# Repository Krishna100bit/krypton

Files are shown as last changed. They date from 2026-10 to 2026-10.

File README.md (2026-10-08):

# OpenPendant

Open-source DIY AI audio pendant. Firmware runs on a **Seeed XIAO nRF52840 Sense**. The necklace captures audio and streams 16 kHz PCM over BLE. Speech-to-text runs on the **phone or laptop**. The MCU never holds an API key.

Record only with an obvious LED and an explicit host subscribe (GATT notify on = recording).

## Hardware

| Part | Notes |
|---|---|
| Seeed XIAO nRF52840 Sense | nRF52840 + onboard PDM mic + LSM6DS3TR-C IMU |
| microSD SPI/SDIO module | 8-pin breakout; VCC = **3V3 only** (never 5V) |
| Ø6 tactile button | 2-pin NO; COM → GND, NO → D1 |
| 22 µF capacitor | Across SD **3V3** and **GND** (16 V ceramic preferred) |
| Perfboard strip | ~8 × 18 holes; XIAO + SD on the front, LiPo on the back |
| WLY602030 1S LiPo | 3.7 V nominal, 300 mAh, 6 × 20 × 30 mm. Open-wire to **BAT+/BAT−**. USB-C charges via BQ25101. |
| USB-C cable | Dev and UF2 flash |

Assembly guide (photos, 3D viewer, printable case): [`docs/pendant_assembly.html`](docs/pendant_assembly.html).

### Wiring (USB at the bottom)

Pin map with the component face toward you:

```text
  XIAO                              microSD (SPI)
  ----                              -------------
  D9  (SCK)  ---------------------> CLK
  D8  (MOSI) ---------------------> CMD
  D7  (MISO) ---------------------> D0
  D6  (CS)   ---------------------> D3
  3V3 ----------------------------> 3V3
  GND ----------------------------> GND
                                    D1, D2  (leave open)

  Button NO  ---------------------> D1
  Button COM ---------------------> GND

  22 µF  across SD 3V3 ↔ SD GND

  LiPo red  --> BAT+     (through the BAT window, last)
  LiPo black -> BAT−
```

```text
Left (USB bottom)     Right (USB bottom)
─────────────────     ──────────────────
5V   (empty)          D0
GND                   D1  button NO
3V3 ──► SD 3V3        D2
D10                   D3
D9  ──► SD CLK        D4  (IMU SDA — do not use)
D8  ──► SD CMD        D5  (IMU SCL — do not use)
D7  ──► SD D0         D6 ──► SD D3 (CS)
```

Firmware remaps SPI2 onto **D9 / D8 / D7** (not the board silk SPI defaults D8 / D10 / D9) and disables UART0 so it cannot steal **D6 / D7**. After soldering, flash over USB (no cell required) and run **Settings → Developer → Run SD test** with a FAT32 card.

## What you get

- **Firmware** (Zephyr / nRF Connect SDK 3.4, Zephyr 4.4): BLE GATT PCM + status, IMU still-sleep (mic off when the board is still, wake on motion), battery voltage / SoC estimate, microSD FAT R/W self-test.
- **Flutter app** in [`app/`](app/): meetings and hold-to-talk notes over BLE, local VAD, **Saaras v4** or on-device **Qwen3-ASR**, optional **OpenAI diarization**, reminders, daily briefings and recaps, persistent follow-ups, Memories search, and local SQLite. Double-click the pendant to ring the connected phone.
- **Laptop tools** in [`tools/`](tools/): BLE capture to WAV, OpenAI or local Whisper.

Protocol, clip schema, and roadmap: [project_context.md](project_context.md). Later sync sketch: [docs/sync_api.md](docs/sync_api.md).

## Firmware

Requires [nRF Connect SDK v3.4.0](https://docs.nordicsemi.com/bundle/ncs-latest/page/nrf/installation.html). Use the Nordic SoftDevice Controller only — do **not** enable `CONFIG_BT_LL_SW_SPLIT` on this board (USB CDC breaks).

```bash
west build -b xiao_ble/nrf52840/sense -d build .
```

Double-tap RESET so the volume `XIAO-SENSE` appears. Finder copy often fails; `dd` works:

```bash
dd if=$(find build -name zephyr.uf2 | head -1) of=/Volumes/XIAO-SENSE/CURRENT.UF2 bs=4096
```

Serial (macOS `screen` often hangs up CDC):

```bash
python3 -m serial.tools.miniterm /dev/cu.usbmodem1101 115200
```

BLE advertises as **OpenPendant**. Disconnect nRF Connect before the app or laptop capture (one connection).

Control UUID `70301104-…`: write `1` / `0` for find-pendant LED flash; write `2` to run the SD mount / write / read test (result in status bytes 8–9).

## Flutter app

```bash
cd app
flutter pub get
flutter run -d macos          # BLE works on Mac
# or a physical iPhone / Android — not the iOS simulator
```

Paste a **Sarvam** key in **Settings** (required for cloud transcripts) and an **OpenAI** key for diarization, day Clean, Memories, and meeting Recap. Keys stay on the host (Keychain / Keystore / app-support file on desktop), never on the pendant.

**Typical day**

1. Connect. Optional **Calibrate** (wear as usual, read the script) sets a personal VAD floor for **notes** only.
2. Optional **Voices**: enroll up to 4 people (2–10 s sample each) if you want named speakers. Turn **Diarization** on in Settings.
3. Start a **meeting** (pendant click, or **Start meeting** in the app) or take a **note** (hold the pendant ~0.7 s, or **Take a note** on the phone). Say “remind me to … at 10 AM” and the phone notifies 15 minutes before; notes without a time come back in an 8 AM reminder until you check them off. **Double-click** rings the connected phone so you can find it. **Find pendant** (connected sheet or Settings → More) is closer/farther from BLE signal, not a compass. Notify stays on while a meeting is armed; LED stays solid. Chunks rotate on IMU sleep, ~30 s raw, or quiet after speech. Local VAD skips the cloud when there is no speech. Meetings use a fixed energy floor (`1e9`, ~0.5 s of speech) so people a metre or two from the chest mic still pass; hiss still has to look like voice. Wearer calibrate does not raise that meeting gate. Double-click a meeting title to rename it.
4. **Transcription:** Settings can use **Saaras v4** (cloud) or **on-device Qwen3-ASR**. Both store the engine text as returned (Hindi in Devanagari when that is what came back). Diarization stays OpenAI and applies to Saaras meetings only. Stop the meeting when you are done. Home groups chunks into one transcript; with diarization on, a long Saaras phrase is split at OpenAI speaker-change times. The transcript tab shows **Transcribing…** until STT catches up.
5. **Close the day:** Home surfaces pending notes and open loops. Tap **Close today** to clean the day’s stored text and create chapters, decisions, follow-ups, and a Memories-ready recap. Follow-ups become checkable notes and join the 8 AM digest until completed. Open the saved review and use **Refresh recap** to replace it after recording more; each run uses OpenAI.

More setup (permissions, IMU debug): [app/README.md](app/README.md).

## Laptop capture

```bash
python3 -m pip install -r tools/requirements.txt
export OPENAI_API_KEY=          # optional; omit for local Whisper
python3 tools/capture_pcm.py --seconds 8 --out capture.wav && \
  python3 tools/transcribe.py capture.wav --backend openai
```

Local Whisper:

```bash
python3 tools/transcribe.py capture.wav --backend local
```

## Consent and sleep

- **Recording:** enable PCM notify. The red LED stays solid while subscribed (armed).
- **IMU sleep:** after ~10 s still, firmware stops the PDM mic and PCM. BLE stays up. Motion wakes the mic. Host VAD drops non-speech before STT.
- **App Sleep** is a BLE disconnect, not IMU sleep.

## Battery

Solder the WLY602030 **red** lead to **BAT+** and **black** to **BAT−** (polarity matters; open wire, no JST). USB-C charges the cell through the XIAO BQ25101. Connect the cell **last**, after the SD / button joints meter clean on USB.

The cell has no fuel-gauge IC. Firmware measures pack voltage (P0.31, 1 MΩ / 510 kΩ divider) and the app maps that to a **rough SoC only when USB is unplugged**. On USB the BQ25101 rail reads ~4.1 V even with no cell, so the UI shows **USB** instead of a fake percent. Treat ~20% as “charge soon.” Keep P0.14 low whenever a cell is attached (firmware hog does this) so P0.31 stays within 3.6 V.

## License

[Apache License 2.0](LICENSE).

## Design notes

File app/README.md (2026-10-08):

# OpenPendant Flutter app

Host for the necklace: arm once → BLE PCM chunks → local VAD → OpenAI → SQLite sessions with wall-clock segments.

## Setup

```bash
cd app
flutter pub get
flutter run -d macos
```

On a phone, use a physical device (BLE does not work in the iOS simulator). A **debug** build cannot be opened from the Home Screen; use `flutter build ios --release` (or profile) for that. If Xcode says the bundle ID `com.openpendant.openpendant` is taken, set a unique id under **Signing & Capabilities** for your Personal Team (do not commit that id).

```bash
flutter devices
flutter run
```

Paste API keys in **Settings**. **Sarvam** is required for cloud transcripts (Saaras v4). Or switch **Transcription** to **On-device** Qwen3-ASR 0.6B (~1 GB once). Transcripts are saved as the engine returns them. **OpenAI** is used for optional meeting diarization (Saaras path only), day Clean, Memories, and meeting Recap.

Disconnect nRF Connect first (the pendant allows one BLE connection). Optional **Auto-connect** in Settings → Behavior links the necklace when it is nearby and the app is open (off by default).

**Find phone:** double-click the pendant button while connected. The phone plays a looping tone (ignores the iOS silent switch) until you tap the screen, double-click again, or 40 seconds pass. Leave the app in the switcher; a force-quit will not receive the button.

**Find pendant:** from the connected sheet or Settings → More. Walk and watch the ring — a stronger BLE signal means closer. It cannot point a compass direction. Current firmware also flashes the board LEDs while you search.

**Note reminders:** “remind me to call mom at 10 AM” notifies 15 minutes before (or 5 minutes / at due if you are already close). Reminder-shaped speech is saved as a **to do**. Everything else is a **thought** (idea / observation) with no checkbox. Library → Notes is a chronological feed with All / Thoughts / To do filters; convert between kinds from the row menu. Untimed to-dos are included in an 8 AM digest until you check them off. iOS will ask for notification permission the first time a reminder is scheduled.

**Daily review:** Home’s briefing surfaces the next pending note and unfinished work. **Close today** sends that day’s stored transcript text and notes to OpenAI, saves a structured recap, and promotes follow-ups/open loops into checkable notes. The recap feeds Memories and optionally Mem0. Open the day review and tap refresh to replace the recap after more recording; refreshing does not create recap copies, but it does use OpenAI again.

If `flutter run` fails with `failed to create ... /.config/flutter`, your `~/.config` may be owned by root:

```bash
sudo chown -R "$(whoami)" ~/.config
mkdir -p ~/.config/flutter
```

On macOS, Xcode must finish first-launch (missing `CoreSimulator` causes `xcodebuild` to fail):

```bash
sudo xcode-select -s /Applications/Xcode.app/Contents/Developer
sudo xcodebuild -runFirstLaunch
brew install cocoapods   # if Flutter reports CocoaPods missing
```

This app disables Swift Package Manager in `pubspec.yaml` because `flutter_secure_storage_macos` does not support it yet.

## Permissions

iOS `ios/Runner/Info.plist`:

- `NSBluetoothAlwaysUsageDescription` / `NSBluetoothPeripheralUsageDescription`
- `UIBackgroundModes`: `bluetooth-central` and `audio` so pendant buttons (including find-phone) and capture still work when the phone is locked (leave the app in the switcher; a force-quit will not wake)
- Local notifications: the first scheduled reminder prompts for alert permission. Timed notes and the morning digest still fire if the app is in the background.

Android `AndroidManifest.xml`:

- `BLUETOOTH`, `BLUETOOTH_ADMIN`, `BLUETOOTH_SCAN`, `BLUETOOTH_CONNECT`, `ACCESS_FINE_LOCATION` (pre-12)
- `POST_NOTIFICATIONS`, `RECEIVE_BOOT_COMPLETED`, `SCHEDULE_EXACT_ALARM` for note reminders

## Consent and armed capture

**Record** = arm: GATT notify on, LED solid, one session id. Capture keeps running until **Stop** or **Sleep**.

Chunks rotate on IMU sleep, ~30 s of raw buffer, or quiet after speech. Each chunk is VAD-gated; silence is not sent to STT. After transcription succeeds or fails, clip WAV files are deleted. Home stitches session text and shows STT spend. While a clip is still in the STT queue, the meeting UI shows **Transcribing…** instead of an empty transcript.

**Meetings** use a fixed VAD energy floor (`VadGate.meetingEnergyFloor` = `1e9`) and at least **0.5 s** of speech-shaped audio. That is about 10× more sensitive than the note default (`1e10`), so quieter / farther talkers on the Knowles SPU0410 chest mic still reach STT. Spectral checks (speech-band ratio and centroid) still drop hiss and rumble. Wearer **Calibrate** does not change the meeting floor.

**Take a note** in the app is tap-to-start / tap-to-save. Pendant BLE still reports `noteHeld: false` while you are not holding the hardware button; those status packets must not stop an in-app note. Hold-to-talk on the necklace is unchanged.

## Mic calibrate

**Calibrate** (home): wear the pendant as you will all day, read the script. The host measures speech-band energy at your mouth–mic distance and sets a personal VAD energy floor for **notes** (saved on this device). Re-calibrate if how you wear it changes. Meetings ignore this floor.

## Voices (speaker names)

**Voices**: enroll up to 4 people (2–10 s sample + name). When **Diarization** is on, meeting clips go to `gpt-4o-transcribe-diarize` with those references; speaker labels are stamped onto the Saaras transcript by time, and a single long Saaras phrase is split at OpenAI speaker-change times. Notes stay on Saaras only (no speaker prefix in the note text).

## IMU sleep debug

After flashing firmware that includes status UUID `70301103-…`, Connect (Record is not required). The **Debug** card shows IMU SLEEP/AWAKE, mic, still meter, battery/USB, and VAD calibrate status.

- Leave the board still ~10 s → IMU **SLEEP**, mic **stopped**.
- Pick it up → **AWAKE**. Mic noise does not block sleep.
- App **Sleep** is a BLE disconnect, not IMU sleep.

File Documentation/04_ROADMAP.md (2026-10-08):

# 04 — Roadmap (Phases, Tracks, Gates)

## 1. How to read this
24 hours, a team, mostly vibe-coded. Work is split into **phases (P0–P11)**, each small enough for one AI-assisted session (30–120 min), with a clear **exit criterion**. Four parallel **tracks**: **A** Flutter app, **B** Backend/AI, **C** Hardware + integration, **D** Pitch/QA.

Priority tags: **[CORE]** required by PS 04 · **[DIFF]** differentiator · **[STRETCH]** cut first.

## 2. Phase table
| Phase | Name | Track | Time box | Depends on | Tag |
|---|---|---|---|---|-----|
| P0 | Foundations, repo audit, contracts | All | 0:00–1:30 | – | CORE |
| P1 | AI core on text (zoning + extraction) | B | 1:30–5:00 | P0 | CORE |
| P2 | ASR + job pipeline + API | B | 3:00–8:00 | P0 | CORE |
| P3 | Flutter capture abstraction + phone recording + upload | A | 1:30–7:00 | P0 | CORE |
| P4 | Zone viewer + minutes UI | A | 6:00–12:00 | P1, P3 | CORE |
| P5 | Locket as AudioSource | C | 6:00–11:00 | P3 | CORE (PS differentiator) |
| P6 | Reminders engine + notifications | A | 9:00–13:00 | P4 | DIFF |
| P7 | Email drafts + approval gate + calendar | A+B | 11:00–15:00 | P4 | DIFF |
| P8 | Speaker enrollment, test, identification | B+A | 10:00–16:00 | P2 | DIFF |
| P9 | Memory search + recap Q&A | B+A | 14:00–18:00 | P2, P4 | DIFF |
| P10 | Offline tiers: Ollama (B) then on-device SLM (C) | B+A | 16:00–20:00 | P9 | STRETCH |
| P11 | Thoughts + daily closing summary | A+B | 18:00–21:00 | P9 | STRETCH |
| P12 | Freeze, polish, demo, pitch, backup video | All | 21:00–24:00 | – | CORE |

## 3. Gates (stop and check)
| Gate | Time | Must be true | If not |
|---|---|---|---|
| G0 | 1:30 | Contracts in repo, fixtures exist, app builds and runs, BLE audit written | Fix before anything else |
| G1 | 5:00 | Text transcript → valid minutes JSON for 3 fixtures | Simplify prompt; use few-shot; smaller schema |
| G2 | 8:00 | Audio file → minutes via API | Use `base` Whisper; skip diarization for now |
| G3 | 12:00 | **Phone recording → upload → zone viewer + minutes works on a real phone** | Drop all stretch work; fix this |
| G4 | 15:00 | Locket recording works OR fallback decided | Ship phone + upload; demo locket as pre-recorded clip |
| G5 | 18:00 | At least 2 of: speaker ID, reminders, drafts, memory working | Cut remaining DIFF items |
| G6 | 21:00 | **Feature freeze** | Only bug fixes after this |

## 4. Phase details
Each phase lists: Goal · Tasks · Deliverables · Exit criteria.

### P0 — Foundations (0:00–1:30)
- Fork/clone the OpenPendant repo into `app/`; run the app on a physical Android phone.
- **Audit:** find BLE service UUIDs, audio characteristic, codec handling, recording storage, any Firebase/auth/backend dependencies (see file 05 §2).
- Create `contracts/minutes.schema.json`, `openapi.yaml` stubs, `contracts/fixtures/` with 3 sample transcripts + expected JSON.
- Put `AGENTS.md` (file 08) in repo root; create `.env.example`.
- Exit: app runs; audit notes written; schema agreed by A and B.

### P1 — AI core on text (1:30–5:00) · Track B
- Implement `LLMClient`, Pydantic models from schema, zoning + extraction prompts (file 06).
- Script `eval/run_eval.py` comparing output with golden fixtures.
- Validator: utterance coverage, no gaps/overlaps, enum checks, date resolution.
- Exit: 3 fixtures produce valid JSON; coverage validator passes; first eval numbers recorded.

### P2 — ASR + pipeline + API (3:00–8:00) · Track B
- `faster-whisper` wrapper with word timestamps → utterances.
- FastAPI endpoints: health, create meeting (audio/transcript), job status, get meeting.
- Job runner with stages and progress.
- Exit: `curl` upload of a WAV returns minutes JSON in a reasonable time.

### P3 — Flutter capture + upload (1:30–7:00) · Track A
- `AudioSource`, `PhoneMicSource`, `RecordingSession`, `WavWriter` (file 05).
- Permissions, foreground service, home screen, record screen with timer + level meter.
- Drift DB with meetings; upload queue with retry; job polling.
- Exit: record 30 s on phone → file on disk → upload works against the stub/real backend.

### P4 — Viewer + minutes UI (6:00–12:00) · Track A
- Meeting list; Meeting detail with tabs: **Transcript (zones)** and **Minutes**.
- Zone colours, legend filter, tap-to-scroll, speaker chips, editable actions table, export.
- Exit: fixture JSON renders correctly; live meeting from P2 renders end to end.

### P5 — Locket source (6:00–11:00) · Track C
- Wrap the existing BLE+Opus code as `LocketBleSource` emitting PCM16 16 kHz.
- Source selector UI, health indicator, disconnect handling, "Continue on phone".
- Exit: 60 s locket recording → WAV plays back clearly → minutes generated.

### P6 — Reminders (9:00–13:00) · Track A
- `ReminderRules.compute()` pure Dart + unit tests; `ReminderScheduler` with notifications; reschedule on edit; overdue nudge.
- Exit: all rule test cases pass; real notification fires on phone (use a test deadline 3 minutes away).

### P7 — Email drafts + approval + calendar (11:00–15:00)
- Backend `draft-email` endpoint; app `DraftStateMachine`; Review & Send screen; confirm dialog; `mailto:`/intent handoff; calendar insert.
- Exit: draft generated, edited, **cannot be sent without the confirm tap** (unit test proves it), handoff opens mail app with content.

### P8 — Speakers (10:00–16:00)
- Enroll endpoint + embeddings; test-sample endpoint + screen; diarize + match in pipeline; rename + auto-enroll.
- Exit: two enrolled teammates are named correctly in a 2-person clip; score shown.

### P9 — Memory + recap (14:00–18:00)
- Chunk/embed on server; `/ask` with citations; app Ask screen; FTS5 index for offline.
- Exit: three prepared questions return correct cited answers.

### P10 — Offline tiers (16:00–20:00)
- B: Ollama client + app tier switch + demo over hotspot with internet off.
- C: model download manager, `local_slm.dart` recap from structured minutes, graceful "unavailable" state.
- Exit: B demonstrated; C either working or visibly marked Experimental.

### P11 — Thoughts + daily summary (18:00–21:00)
- Thought button + voice trigger detection; recap + research + brainstorm.
- `DailySummary` template builder + 21:00 notification; optional SLM/LLM polish.
- Exit: one thought end to end; summary notification fires.

### P12 — Freeze and ship (21:00–24:00)
- Bug bash with checklist (file 09), seed demo data, record backup video, rehearse pitch ×3, build release APK, charge phone, pack cables.

## 5. Cut lines (in order)
1. On-device SLM (keep Tier B) → 2. Thoughts research/brainstorm → 3. Daily summary polish → 4. Names vault → 5. Gmail API (keep mailto) → 6. Speaker auto-enroll → 7. Locket live (keep pre-recorded locket clip).
**Never cut:** phone recording, zone viewer, minutes, approval gate, one reminder demo.

## 6. Team allocation
| Role | People | Owns |
|---|---|---|
| Flutter lead | 1–2 | P3, P4, P6, P7 UI |
| AI/backend lead | 1 | P1, P2, P8, P9 |
| Hardware/integration | 1 (VENOM likely) | P5, P10-B, deployment, final demo rig |
| Pitch/QA | 1 | file 09, slides, test data |
Solo? Order: P0 → P1 → P2 → P3 → P4 → P6 → P5 → P7, then whatever time allows.

## 7. Post-hackathon roadmap
v2.1 sync + accounts + encrypted storage · v2.2 streaming live captions · v2.3 battery + enclosure + LED + VAD firmware · v2.4 Slack/Notion/Calendar API integrations · v2.5 iOS · v3 team workspaces, multilingual, fine-tuned zoning model.

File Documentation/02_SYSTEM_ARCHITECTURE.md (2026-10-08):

# 02 — System Architecture

## 1. Context diagram
```mermaid
flowchart LR
  subgraph Wearable
    L[XIAO nRF + mic<br/>OpenPendant firmware]
  end
  subgraph Phone[Flutter App]
    SRC[AudioSource<br/>PhoneMic / LocketBLE]
    REC[RecordingSession + WAV writer]
    DB[(SQLite + FTS5)]
    ROUTER[InferenceRouter]
    REM[Reminder Engine<br/>rule-based]
    SLM[On-device ASR + SLM<br/>optional]
    UI[Viewer / Minutes / Ask / Drafts]
  end
  subgraph Server[Backend: laptop or cloud]
    API[FastAPI]
    ASR[faster-whisper]
    DIA[pyannote + SpeechBrain]
    LLM[LLM: Claude API or Ollama]
    VEC[(Chroma + SQLite)]
  end
  EXT[Calendar app / Mail app / Gmail drafts / Search API]
  L -- BLE Opus --> SRC
  SRC --> REC --> DB
  REC --> ROUTER
  ROUTER -- Tier A/B --> API
  ROUTER -- Tier C --> SLM
  API --> ASR --> DIA --> LLM --> VEC
  API -- minutes JSON --> DB
  SLM --> DB
  DB --> UI
  DB --> REM
  UI -- user taps --> EXT
```

## 2. Components
| Component | Responsibility | Tech |
|---|---|---|
| Firmware | Capture mic, Opus encode, stream over BLE (unchanged from v1) | nRF Connect SDK / Zephyr (existing) |
| AudioSource layer | Uniform PCM stream from either input | Dart |
| RecordingSession | Chunked WAV on disk, level meter, duration, recovery | Dart |
| InferenceRouter | Chooses Tier A/B/C from connectivity and settings | Dart |
| Backend API | Jobs, pipeline, memory, drafts | FastAPI |
| ASR | Timestamped transcript | faster-whisper |
| Diarization + Speaker ID | Turns + names | pyannote 3.1, SpeechBrain ECAPA |
| LLM service | Zoning, extraction, recap, drafts, intent | Claude API / Ollama (Qwen, Llama) behind one interface |
| Memory | Chunk, embed, retrieve, cite | Chroma + bge-small; FTS5 on device |
| Reminder Engine | Deterministic scheduling | Dart + flutter_local_notifications |
| Draft Manager | Draft state machine + approval gate | Dart |
| Scheduler | Daily summary, overdue nudges | Local notifications |

## 3. Key data flows

### 3.1 Record → minutes
```mermaid
sequenceDiagram
  participant U as User
  participant A as App
  participant S as Backend
  U->>A: Tap Record (Phone or Locket)
  A->>A: AudioSource -> WAV (16k mono)
  U->>A: Stop
  A->>A: Save meeting row (status=recorded)
  A->>S: POST /v1/meetings (audio)
  S-->>A: meeting_id, job_id
  S->>S: ASR -> diarize -> speaker match
  S->>S: LLM zoning + extraction (validated JSON)
  S->>S: Chunk + embed for memory
  A->>S: poll /v1/jobs/{id}
  S-->>A: minutes JSON
  A->>A: Store, index FTS5, schedule reminders
  A-->>U: Zone viewer + minutes
```

### 3.2 Action → reminder (fully local)
Action saved with deadline + priority → `ReminderRules.compute()` → rows in `reminders` → `zonedSchedule` notifications. Editing the action cancels and recomputes. No network involved.

### 3.3 Action → email draft with human approval
```mermaid
stateDiagram-v2
  [*] --> GENERATED: tap "Draft email" (LLM or template)
  GENERATED --> EDITED: user edits
  GENERATED --> DISCARDED
  EDITED --> PENDING_APPROVAL: user opens Review & Send
  GENERATED --> PENDING_APPROVAL
  PENDING_APPROVAL --> APPROVED: user taps "Send" in confirm dialog
  PENDING_APPROVAL --> EDITED: back
  APPROVED --> SENT: mail client / Gmail API returns success
  APPROVED --> FAILED
```
Only `APPROVED` may call the send/handoff function, and `APPROVED` can only be set by a tap in the confirm dialog (see file 07).

### 3.4 Ask memory
Query → (online) embed + Chroma top-k + LLM answer with citations; (offline) FTS5 BM25 top-k → SLM or extractive answer from structured minutes.

## 4. Deployment topologies
| Tier | Where AI runs | Internet needed | Use |
|---|---|---|-----|
| A Cloud | Backend with Claude API + faster-whisper | Yes | Best quality, main demo |
| B Local server | Laptop backend + Ollama (Qwen/Llama) + faster-whisper, phone on same hotspot/LAN | No | "Offline" demo with strong quality |
| C On-device | whisper.cpp/sherpa-onnx + small LLM on phone | No | Offline recap; stretch |

Fallback chain: A → B → C → "recorded, will process later" queue.

## 5. Failure modes and mitigations
| Failure | Detection | Behaviour |
|---|---|---|
| BLE drop | No packets for 3 s | Banner, keep partial WAV, offer Continue on phone |
| Backend unreachable | Timeout / health check | Queue upload, retry with backoff, fall to next tier |
| LLM invalid JSON | Pydantic validation fails | Repair prompt once, then cached/simple heuristic zoning |
| Whisper slow | Job progress stalls | Smaller model option, chunked processing |
| Notification permission denied | Runtime check | In-app banner explaining; reminders listed in-app |
| Exact alarm not permitted | Android check | Fall back to inexact scheduling, warn user |
| App killed mid-recording | Partial WAV exists on restart | Recovery dialog to finalize |

## 6. Security and privacy
- Consent prompt + recording indicator (UI badge; LED if firmware supports it).
- API keys only on the backend; the app uses a single backend URL + a shared secret token for the hackathon.
- Data at rest: app-private storage; delete cascades to audio, transcript, embeddings.
- No automatic outbound messages. Network egress is limited to our backend and optional search for thoughts.
- Logs never contain transcript text in production mode.

## 7. Observability (cheap but useful)
Per-job timings (ASR, diarize, LLM), model names, token counts, validation failures; a `/debug` page in the backend and a hidden debug screen in the app showing the last job JSON.

## 8. Post-hackathon scaling notes
Accounts + sync, queue (Redis/RQ), object storage, streaming ASR, per-user vector stores, encrypted storage, iOS, enclosure + battery, firmware VAD to save power.

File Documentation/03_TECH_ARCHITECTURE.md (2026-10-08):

# 03 — Technical Architecture

## 1. Stack summary
| Layer | Choice | Notes |
|---|---|---|
| Mobile app | Flutter (existing OpenPendant app) | Keep its state management (likely Provider); do not migrate |
| BLE | `flutter_blue_plus` (or whatever the repo already uses) | Keep existing connection code |
| Audio decode | Existing Opus decode path in the repo (e.g., `opus_dart`/`opus_flutter`) | Verify in P0 |
| Phone recording | `record` package (`startStream`, PCM16, 16 kHz, mono) | |
| WAV writing | Own small `WavWriter` (44-byte header + PCM) | |
| Local DB | `drift` (SQLite) + FTS5 | Local-first |
| HTTP | `dio` with retry interceptor | |
| Notifications | `flutter_local_notifications` + `timezone` | Exact alarms on Android |
| Calendar | `add_2_calendar` (native insert screen) | User confirms |
| Email handoff | `url_launcher` `mailto:` / Android share intent; optional Gmail API `drafts.create` | Human-final |
| Foreground service | `flutter_foreground_task` | Long recordings |
| Backend | Python 3.11, FastAPI, Pydantic v2, Uvicorn | |
| Jobs | FastAPI `BackgroundTasks` + SQLite job table | Redis only if time |
| ASR | `faster-whisper` (`small` default, `medium`/`large-v3` if GPU) | CTranslate2 |
| Diarization | `pyannote.audio` 3.1 (HF token) | Or WhisperX |
| Speaker embeddings | SpeechBrain `spkrec-ecapa-voxceleb` | Enrollment + matching |
| LLM (A) | Claude API | JSON-structured output with validation |
| LLM (B) | Ollama: `qwen2.5:7b-instruct` or `llama3.1:8b` | Local server |
| SLM (C) | Qwen2.5-1.5B-Instruct Q4_K_M (≈1 GB, Apache-2.0) or Gemma-class 1–2B | On phone; check license and size |
| On-device ASR (C) | whisper.cpp (`tiny.en`/`base.en`) or sherpa-onnx | Stretch |
| Embeddings | `bge-small-en-v1.5` or `all-MiniLM-L6-v2` | Server |
| Vector store | ChromaDB (persistent) | Server |
| Research | Tavily (or similar) search API | Thoughts only |
| Tests | pytest, `flutter test`, eval script | |

> Always verify package names, versions and licenses against pub.dev / PyPI / model cards on day 0. Packages in the on-device LLM space move fast.

## 2. Flutter app architecture (feature-first layers)
```
app/lib/
├─ core/            # env, theme, router, di, logger, permissions
├─ audio/
│  ├─ audio_source.dart            # abstract interface
│  ├─ phone_mic_source.dart
│  ├─ locket_ble_source.dart       # wraps existing BLE+Opus code
│  ├─ recording_session.dart       # owns source, WavWriter, timers
│  └─ wav_writer.dart
├─ data/
│  ├─ db/ (drift tables, DAOs, FTS5)
│  ├─ api/ (dio client, DTOs generated from contracts)
│  └─ repositories/ (meetings, actions, speakers, thoughts, drafts)
├─ ai/
│  ├─ inference_router.dart        # Tier A/B/C selection
│  ├─ remote_pipeline.dart
│  └─ local_slm.dart               # optional
├─ domain/
│  ├─ models/ (Meeting, Segment, Action, Decision, Draft…)
│  ├─ reminder_rules.dart          # pure Dart, fully unit tested
│  ├─ daily_summary.dart           # pure Dart template builder
│  └─ draft_state_machine.dart
├─ features/
│  ├─ home/  record/  meetings/  viewer/  minutes/
│  ├─ actions/  drafts/  ask/  thoughts/  speakers/  settings/
└─ main.dart
```
Rules: UI never calls BLE or HTTP directly; features call repositories/services. `domain/` has no Flutter imports (testable).

### AudioSource interface
```dart
abstract class AudioSource {
  String get id;                       // 'phone' | 'locket'
  Stream<Uint8List> get pcm16;         // 16 kHz mono little-endian PCM16
  Stream<SourceHealth> get health;     // connected, rssi, dropped packets, level
  Future<void> start();
  Future<void> stop();
}
```

## 3. Backend architecture
```
backend/app/
├─ main.py
├─ api/        meetings.py speakers.py ask.py actions.py thoughts.py summary.py health.py
├─ pipeline/   ingest.py asr.py diarize.py speaker_match.py zone.py extract.py chunk.py
├─ llm/        base.py claude_client.py ollama_client.py prompts/ schemas.py
├─ speakers/   enroll.py embeddings.py
├─ memory/     store.py retrieve.py answer.py
├─ jobs/       runner.py models.py
├─ core/       config.py db.py logging.py
└─ tests/
```
`llm/base.py` defines `LLMClient.generate_json(system, user, schema) -> dict` so Tier A and B are interchangeable.

## 4. Data schemas

### 4.1 App DB (SQLite via drift)
```sql
meetings(id TEXT PK, title TEXT, started_at INT, duration_s INT, source TEXT,        -- phone|locket|upload
         audio_path TEXT, status TEXT,                                               -- recorded|uploading|processing|ready|failed
         summary TEXT, minutes_json TEXT, server_id TEXT);
utterances(id TEXT PK, meeting_id TEXT, idx INT, speaker_id TEXT, start_s REAL, end_s REAL, text TEXT);
segments(id TEXT PK, meeting_id TEXT, idx INT, zone TEXT,                            -- discussion|decision|action
         start_idx INT, end_idx INT, start_s REAL, end_s REAL, summary TEXT, confidence REAL);
decisions(id TEXT PK, meeting_id TEXT, segment_id TEXT, text TEXT, decided_by TEXT, rationale TEXT);
actions(id TEXT PK, meeting_id TEXT, segment_id TEXT, task TEXT, owner_name TEXT, owner_speaker_id TEXT,
        owner_inferred INT, deadline_ts INT NULL, deadline_inferred INT, priority TEXT, status TEXT,   -- open|done|snoozed
        source_quote TEXT, created_at INT);
reminders(id TEXT PK, action_id TEXT, fire_at INT, kind TEXT, notif_id INT, state TEXT);              -- pending|fired|cancelled
email_drafts(id TEXT PK, action_id TEXT, to_json TEXT, subject TEXT, body TEXT, state TEXT,
             created_at INT, approved_at INT NULL, sent_at INT NULL);
speakers(id TEXT PK, name TEXT, enrolled_at INT);                                    -- embeddings live on server
thoughts(id TEXT PK, text TEXT, created_at INT, recap TEXT, research_md TEXT, sources_json TEXT, tags TEXT);
names_vault(id TEXT PK, name TEXT, note TEXT, created_at INT);
CREATE VIRTUAL TABLE chunks_fts USING fts5(meeting_id UNINDEXED, ref UNINDEXED, text);
```

### 4.2 Server DB (SQLite) additions
`jobs(id, meeting_id, stage, progress, error, timings_json)`, `speaker_embeddings(speaker_id, vector BLOB, samples INT)`, plus a Chroma collection `chunks` (metadata: meeting_id, start_s, end_s, zone, speakers).

## 5. API contract (OpenAPI source: `contracts/openapi.yaml`)
| Method | Path | Body | Returns |
|---|---|---|---|
| GET | `/v1/health` | – | status, models loaded, tier |
| POST | `/v1/meetings` | multipart audio **or** JSON transcript, `title`, `started_at`, `source` | `{meeting_id, job_id}` |
| GET | `/v1/jobs/{id}` | – | `{stage, progress, error?}` |
| GET | `/v1/meetings` | – | list |
| GET | `/v1/meetings/{id}` | – | full minutes JSON (schema in file 06) |
| POST | `/v1/speakers/enroll` | audio, name | `{speaker_id, quality}` |
| POST | `/v1/speakers/test` | audio (~5 s) | `{matches:[{name, score}], best, threshold}` |
| GET | `/v1/speakers` | – | list |
| POST | `/v1/ask` | `{question, meeting_id?, filters?}` | `{answer, citations:[{meeting_id, start_s, quote}]}` |
| POST | `/v1/actions/{id}/draft-email` | `{tone?}` | `{subject, body, suggested_to:[]}` (**generates text only; never sends**) |
| POST | `/v1/thoughts` | text or audio | `{id, recap}` |
| POST | `/v1/thoughts/{id}/research` | – | `{research_md, sources}` |
| POST | `/v1/brainstorm` | `{thought_id, messages[]}` | `{reply}` |
| POST | `/v1/recap` | `{meeting_id}` | `{recap}` (Tier A/B) |

Auth for hackathon: header `X-Krypton-Token` from env. Errors use `{error:{code,message}}`.

## 6. Configuration
`backend/.env`: `ANTHROPIC_API_KEY`, `LLM_PROVIDER=claude|ollama`, `OLLAMA_URL`, `WHISPER_MODEL=small`, `HF_TOKEN`, `TAVILY_API_KEY`, `KRYPTON_TOKEN`, `DATA_DIR`.
App: server URL, tier preference (Auto/A/B/C), recap model, reminder quiet hours, daily summary time.

## 7. Performance budget (targets)
| Stage | Budget (10 min audio, Tier A, decent CPU or GPU) |
|---|---|
| Upload | < 5 s on Wi-Fi |
| ASR (`small`, GPU) | ~20–40 s; CPU may be 2–4 min, so use `base` for demos on CPU |
| Diarization | 30–60 s |
| LLM zoning + extraction | 15–40 s |
| Embedding + store | < 5 s |
Pre-process demo clips ahead of time; show a progress bar for live runs.

## 8. Model notes
- **Whisper:** `small.en` for English demos, multilingual `small` for Hinglish; word timestamps on.
- **SLM:** keep context ≤ 2k tokens by feeding structured minutes; Q4 quantization; one model download shown in Settings with a size warning.
- Do not claim on-device diarization unless it actually works; mark it experimental.

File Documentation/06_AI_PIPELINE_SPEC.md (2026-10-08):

# 06 — AI Pipeline Specification

## 1. Pipeline stages
```
audio/transcript → [1 ingest+normalize] → [2 ASR] → [3 diarize] → [4 speaker match]
→ [5 utterance build] → [6 zoning] → [7 extraction] → [8 validate/repair] → [9 chunk+embed] → minutes JSON
```
Transcript-only input skips stages 1–4 (speakers parsed from labels if present).

### Stage notes
1. **Normalize:** ffmpeg → 16 kHz mono WAV, loudness normalize lightly.
2. **ASR:** faster-whisper, `word_timestamps=True`, VAD filter on, language auto or forced. Output words with times.
3. **Diarization:** pyannote 3.1 → speaker turns. Merge words into turns by timestamp overlap.
4. **Speaker match:** for each diarized speaker, average ECAPA embeddings of its longest clean turns (≥ 3 s total, up to 30 s); cosine against enrolled embeddings; assign if score ≥ threshold and margin over second-best ≥ 0.05, else "Speaker N". Thresholds are **calibrated** on your own samples (SpeechBrain's default verification cutoff is around 0.25 for its own scoring; tune on your data and show the score in UI).
5. **Utterances:** merge consecutive words from the same speaker with gaps < 1.0 s; split at > 25 s. Number them `u0…uN`. This index is the shared coordinate system for everything after.

## 2. Output schema (`contracts/minutes.schema.json`)
```json
{
  "meeting": {"id": "", "title": "", "date": "2026-10-09", "duration_s": 0, "language": "en"},
  "speakers": [{"id": "S1", "name": "Rahul", "matched": true, "confidence": 0.82}],
  "utterances": [{"idx": 0, "speaker_id": "S1", "start": 0.0, "end": 6.2, "text": ""}],
  "segments": [{
    "id": "seg_1", "zone": "discussion|decision|action",
    "start_idx": 0, "end_idx": 5, "summary": "", "speaker_ids": ["S1"], "confidence": 0.85
  }],
  "decisions": [{"id": "d1", "text": "", "decided_by": ["S1"], "rationale": null, "segment_id": "seg_2"}],
  "actions": [{
    "id": "a1", "task": "",
    "owner": {"speaker_id": "S2", "name": "Priya", "inferred": true, "confidence": 0.7},
    "deadline": {"iso": "2026-10-12T17:00:00+05:30", "raw": "by Monday evening", "inferred": false},
    "priority": "high|medium|low", "segment_id": "seg_3", "source_utterance_idx": 14
  }],
  "summary": "", "open_questions": [""], "names_mentioned": [""]
}
```
Rules: segments are **contiguous, ordered, non-overlapping, and cover every utterance**; every decision/action references a segment; `source_utterance_idx` must exist.

## 3. Zone definitions (use verbatim in prompts)
- **discussion** — ideas, questions, explanations, status updates, debate, brainstorming; no commitment reached.
- **decision** — the group agrees or the leader settles something ("let's go with…", "agreed", "we'll use…"); capture what and who.
- **action** — a person commits or is assigned to do something later ("I'll send…", "Priya, can you…" + agreement); needs task, owner, deadline if stated.
A segment has exactly one zone (the dominant one); a decision and an action can be adjacent segments. Short acknowledgements ("okay", "yes") attach to the segment they confirm.

## 4. Zoning + extraction prompt (starting point)
**System:**
```
You turn meeting transcripts into structured minutes. The transcript is a numbered list of utterances:
[idx] Speaker: text
Rules:
1. Output ONLY valid JSON matching the provided schema. No prose, no code fences.
2. Segment the transcript into contiguous segments that cover EVERY utterance exactly once, in order.
3. Label each segment: discussion, decision, or action using the definitions provided.
4. Decisions: state what was decided in one sentence; list who decided; add rationale only if stated.
5. Actions: task as an imperative sentence; owner = the person who commits or is clearly assigned. If unclear use null. Never guess names that are not in the transcript.
6. Deadlines: copy the raw phrase and resolve it to an ISO-8601 datetime using the meeting date {meeting_date} and timezone {tz}. If no deadline is stated, set deadline to null. Do not invent deadlines.
7. Priority: high if urgent/blocking/explicitly important or due within 48h; low if "whenever/nice to have"; otherwise medium.
8. Reference evidence only by utterance index, never by quoting.
9. Be conservative: if unsure whether something is an action, label the segment discussion and add the item to open_questions.
```
**User:** the numbered transcript + meeting metadata + one few-shot example (a 12-utterance example with correct JSON). Keep few-shot in `backend/app/llm/prompts/zoning_fewshot.json`.

### Chunking for long meetings
> 25k tokens: split by ~150 utterances with 10 overlap, run per chunk, then merge: reindex, join adjacent same-zone segments across chunk boundary, de-duplicate decisions/actions by normalized text similarity (≥ 0.85).

### Validation and repair (stage 8)
1. JSON parse; Pydantic validation.
2. Coverage check (no gaps/overlaps). Auto-repair: fill gaps with `discussion`, trim overlaps.
3. Referential integrity (segment ids, utterance indices).
4. Date sanity: deadline not before meeting date; if before, flag `needs_review`.
5. If invalid after auto-repair: one **repair call** with the validator's error list; else fall back to heuristic zoning (keyword rules: "agreed/decided/let's go with" → decision; "I'll/will/by <date>/can you" → action).

## 5. Owner and deadline inference rules
| Pattern | Owner |
|---|---|
| "I'll do X" | speaker |
| "Priya, can you do X?" + "sure/yes/okay" from Priya | Priya |
| "We should do X" (no name) | null (flag Unassigned) |
| "Rahul will handle X" | Rahul |
Deadlines: "tomorrow", "Friday", "end of week", "next Monday", "in two days", "EOD" resolve relative to meeting date; default time 17:00 local if only a date is given, marked `time_inferred`.

## 6. Speaker enrollment
- Record 10–20 s of natural speech (provide a short prompt to read). Reject if SNR is too low or < 8 s of speech (VAD).
- Store the mean embedding plus count; allow adding more samples to improve.
- **Test sample endpoint:** 5 s audio → embeddings → cosine to all enrolled → return ranked list, best score, and the threshold used.
- Post-meeting rename of "Speaker N" → name; option "Enroll from this meeting" using their best turns.

## 7. Memory and recap (RAG)
- **Chunks:** per segment (≈ 100–300 tokens) with metadata (meeting, time, zone, speakers). Also index each decision and action as its own chunk (high signal).
- **Embeddings:** bge-small/MiniLM; Chroma persistent.
- **Retrieval:** top-8 with filters (meeting, zone, speaker, date); optional keyword boost via SQLite FTS.
- **Answer prompt:** "Answer only from the context. Cite as [meeting title, mm:ss]. If the context does not contain the answer, say you could not find it."
- **Recap command:** summarize one meeting from its minutes JSON: 3-line summary + decisions + top actions.

## 8. Offline tiers
**Tier B (local server):** same pipeline; `LLM_PROVIDER=ollama`, a 7–8B instruct model. Expect weaker JSON adherence than Claude: use lower temperature (0.1), smaller schema chunks, and the repair step more often. Test early (P10 gate) rather than at the end.

**Tier C (on-device SLM):**
- Scope: **recap and Q&A over already-structured minutes**, not full zoning. Input is the minutes JSON reduced to ≈ 300–800 tokens.
- Model: Qwen2.5-1.5B-Instruct Q4_K_M (≈ 1 GB) default; alternatives: a 1–2B Gemma-class or Llama-3.2-1B. Check each model's license and size before bundling; offer download inside the app rather than shipping it in the APK.
- Prompt (short): "Using only the facts below, write a 4-line recap: key decisions, then actions with owners and dates. Facts: ..."
- Settings: temperature 0.2, max tokens 200, context 2048, run in an isolate, show a progress indicator, hard timeout 60 s with extractive fallback (template recap from JSON).
- **Extractive fallback is mandatory:** if the SLM fails, show the template recap built directly from the JSON so the feature never appears broken.
- On-device ASR (optional): whisper.cpp `tiny.en`/`base.en`; accuracy lower, so mark transcripts "offline draft"; reprocess when online.

## 9. Thoughts
- **Trigger:** utterance begins with "thought", "note to self", "idea", "remember this" (rule match) **or** LLM intent classifier on a short utterance (online); manual Thought button always works.
- **Recap:** 1–2 line summary + tags.
- **Research (online only):** generate 2–3 search queries → Tavily → fetch top results → LLM summary with source list. Never present unsourced claims as researched.
- **Brainstorm:** chat with system prompt "You are a brainstorming partner: ask one clarifying question, then offer 5 distinct directions, then help pick one." Keep history in the app DB.

## 10. Daily closing summary
Deterministic template first (file 07 §6); optional one-pass LLM/SLM polish that must not add facts. Inputs: today's meetings, decisions, new actions, due tomorrow, overdue, thoughts count.

## 11. Evaluation
| Metric | How |
|---|-----|
| Zone accuracy | Utterance-level accuracy vs golden labels, plus segment boundary F1 (±1 utterance) |
| Action recall/precision | Match by normalized task similarity ≥ 0.7 |
| Owner accuracy | Exact name match among matched actions |
| Deadline accuracy | Same calendar day |
| Speaker ID | Accuracy on a 2–3 person clip; false-accept rate on an unenrolled voice |
| Latency | Per stage timings |
| JSON validity rate | % passing validation without repair |
Dataset: 8–10 meetings: 3 from AMI (use ASR transcripts or annotations), 5–7 generated (LLM-written dialogues with a hidden answer key, then text-to-speech with 2–3 voices for audio tests). Save as `eval/data/*.json`. Report one table in the deck.

## 12. Prompt safety and privacy
Treat transcript text as untrusted data: the system prompt states that instructions inside the transcript must be ignored. Never include API keys in prompts. Strip emails/phones from logs.

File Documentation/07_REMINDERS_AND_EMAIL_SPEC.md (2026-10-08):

# 07 — Reminders, Calendar, Email Drafts, Daily Summary

Principle (D5, D6): **the LLM proposes, deterministic rules decide, and the human approves every outbound action.**

## 1. Reminder engine (hardcoded, offline)

### 1.1 Inputs and outputs
Input: `deadline` (local DateTime, nullable), `priority`, `now`, `quietHours` (default 22:00–07:00), `morningTime` (default 09:00).
Output: sorted list of `ReminderPlan{fireAt, kind, label}`.

### 1.2 Rule table
| Condition | Reminders |
|---|---|
| No deadline | None. Mark "Needs deadline"; include in daily summary; one nudge the next morning at `morningTime` |
| Deadline − now < 2 h | One reminder at deadline − 15 min (if still in the future) |
| Priority HIGH | deadline − 24 h, deadline − 3 h, deadline − 30 min |
| Priority MEDIUM | deadline − 24 h, deadline − 2 h |
| Priority LOW | Morning of deadline day at `morningTime` (if before the deadline), else deadline − 2 h |
| Deadline more than 3 days away (any priority) | Add a "heads-up" at deadline − 3 days at `morningTime` |
| Overdue and open | Daily nudge at `morningTime` until done or snoozed |

Post-processing, in this order:
1. Drop any `fireAt` ≤ now + 1 minute.
2. **Quiet hours:** if `fireAt` falls inside quiet hours, move it to the next `morningTime` **if that is still before the deadline**; otherwise move it to deadline − 30 min; if that is also quiet and the deadline is within quiet hours, keep the original (never silently drop a high-priority reminder).
3. Merge reminders within 10 minutes of each other (keep the later one).
4. Cap at 5 reminders per action.

### 1.3 Dart skeleton (`domain/reminder_rules.dart`)
```dart
enum Priority { high, medium, low }

class ReminderPlan {
  final DateTime fireAt;
  final String kind;   // 'heads_up' | 't_minus' | 'morning' | 'overdue' | 'final'
  final String label;  // human-readable, shown in the action detail
  const ReminderPlan(this.fireAt, this.kind, this.label);
}

List<ReminderPlan> computeReminders({
  required DateTime? deadline,
  required Priority priority,
  required DateTime now,
  TimeOfDay quietStart = const TimeOfDay(hour: 22, minute: 0),
  TimeOfDay quietEnd   = const TimeOfDay(hour: 7,  minute: 0),
  TimeOfDay morning    = const TimeOfDay(hour: 9,  minute: 0),
}) { /* pure function: no Flutter plugins, no clock access */ }
```
`now` is always injected so tests are deterministic.

### 1.4 Scheduler
- `ReminderScheduler.sync(action)`: cancel existing reminders for the action → compute → insert rows → `zonedSchedule` each (`androidScheduleMode: exactAllowWhileIdle`) with a stable notification id (`hash(actionId + kind)`).
- Triggers for `sync`: action created, edited, marked done (cancel all), snoozed (+1 h / tomorrow morning).
- Notification actions: **Done**, **Snooze 1h**, **Open**. Tapping opens the action detail.
- On app start and after boot: re-sync all open actions (idempotent).
- Channels: `reminders` (high importance), `daily_summary` (default).
- Permission flow: request notifications; on Android 12+ check exact alarm permission and deep link to settings if missing; show an in-app banner if disabled.
- The reminders list is also visible in-app so the feature is demonstrable even if the OS blocks notifications.

### 1.5 Required unit tests (all must pass before demo)
| # | now | deadline | priority | Expected |
|---|-----|---|---|---|
| 1 | Mon 10:00 | Fri 17:00 | high | Thu 17:00, Fri 14:00, Fri 16:30, plus heads-up Tue 09:00 (>3 days) |
| 2 | Mon 10:00 | Tue 12:00 | medium | Mon 12:00 (24 h earlier = Mon 12:00), Tue 10:00 |
| 3 | Mon 10:00 | Mon 11:30 | high | Single: Mon 11:15 |
| 4 | Mon 10:00 | Wed 08:00 | medium | T−24h = Tue 08:00 → fine; T−2h = Wed 06:00 is quiet → moved to Wed 07:30 |
| 5 | Mon 10:00 | null | any | [] and `needsDeadline` flag |
| 6 | Mon 10:00 | Sun (past) | any | [] and overdue nudge schedule |
| 7 | Mon 23:00 | Tue 09:00 | high | T−24h dropped (past); T−3h = Tue 06:00 is quiet and next morning 09:00 is not before the deadline → moved to deadline − 30 min = Tue 08:30, which merges with the T−30m reminder → single Tue 08:30 |
| 8 | Mon 10:00 | Mon 10:30 | low | Single reminder Mon 10:15 (the "< 2 h" rule overrides priority) |
| 9 | any | any | any | No two reminders within 10 min; ≤ 5 total |
If you change the rules, update the expected values here and in the test file together, and keep these scenarios.

## 2. Calendar (human-confirmed)
- "Add to calendar" button on an action → `add_2_calendar` opens the native insert screen prefilled (title = task, start = deadline − 30 min or deadline, notes = meeting link/quote). The user taps Save.
- Optional upgrade: Google Calendar API insert after an explicit confirm dialog showing the event details.
- Never create events in the background.

## 3. Email drafts with human-final approval

### 3.1 Flow
1. User taps **Draft email** on an action (or "Draft follow-up for this meeting").
2. App calls `/v1/actions/{id}/draft-email` (Tier A/B) or builds a **template draft** locally if offline.
3. Draft saved as `GENERATED`. UI opens the draft editor (To, Cc, Subject, Body — all editable).
4. User taps **Review & Send** → full-screen preview, "To" recipients chips, attachments (none by default).
5. User taps **Send** → confirmation dialog: "Send this email to *name@example.com*?" with **Cancel / Send**.
6. Only the Send button inside this dialog sets `APPROVED` and calls the handoff.

### 3.2 State machine (`domain/draft_state_machine.dart`)
States: `GENERATED, EDITED, PENDING_APPROVAL, APPROVED, SENT, FAILED, DISCARDED`.
Transitions: as in file 02 §3.3. Any edit after `PENDING_APPROVAL` returns to `EDITED` (approval is invalidated by changes).

### 3.3 Invariants (write tests for each)
1. `sendHandoff()` throws unless `draft.state == APPROVED` **and** the approval token was minted by `ConfirmSendDialog` in the same session.
2. Approval token expires after 60 seconds and is single-use.
3. Editing any field after approval resets the state.
4. The backend `draft-email` endpoint returns text only; it has no send capability and no mail credentials.
5. Recipients are never auto-filled from an LLM guess: `suggested_to` is shown as chips labeled "Suggested — confirm"; unconfirmed addresses block the Send button.
6. No background job, notification action, or deep link can trigger send.
7. Logging never records the body of drafts.

### 3.4 Handoff options
| Option | How | Pros | Cons |
|---|-----|---|---|
| **Default: mail client** | `mailto:` URL or Android `ACTION_SENDTO` with subject/body → user's mail app opens prefilled; user presses Send there | No OAuth, offline-friendly, human-final by nature | Two taps; long bodies may truncate in some clients |
| Upgrade: Gmail API draft | `users.drafts.create` (scope `gmail.compose`), then open the draft in Gmail | Real Gmail draft | OAuth setup; the scope technically allows sending, so the code must only call `drafts.create` |
| Upgrade: Gmail API send | `users.messages.send` after the confirm dialog | One-tap send | Highest risk; build last or skip |
Recommended for the hackathon: default option, with the in-app approval flow in front of it so the "human permission" story is visible to judges.

### 3.5 Draft generation prompt
```
Write a short, polite follow-up email for this action item from a meeting.
Context: meeting title, date, action task, owner, deadline, relevant decision (if any).
Rules: max 120 words; plain text; start with a greeting using the recipient's name only if provided; include the task and deadline once; no invented facts, no promises beyond the task; end with a thanks and the sender's first name placeholder {sender_name}.
Return JSON: {"subject": "...", "body": "..."}
```
Offline template: `Subject: Follow-up: {task}` / body with fixed text and fields filled from the action.

## 4. Task "automation" scope (what is automatic and what is not)
| Step | Automatic? |
|---|---|
| Extract tasks, owners, deadlines | Yes (LLM) |
| Compute reminder schedule | Yes (rules) |
| Fire notifications | Yes (local) |
| Create calendar event | **No**, user saves in the calendar screen |
| Create email draft text | Yes (text only) |
| Send email | **No**, user approves explicitly |

## 5. Names and notes vault (stretch)
Store important names/phrases flagged by the user or extracted as `names_mentioned`; searchable list with the meeting they came from. No sensitive categories auto-tagged.

## 6. Daily closing summary

### 6.1 Template (deterministic)
```
Today you had {n_meetings} meeting(s) · {n_decisions} decision(s) · {n_actions} new action(s).
Due tomorrow: {due_tomorrow_list or "nothing"}.
Overdue: {overdue_count}.   Needs a deadline: {nodeadline_count}.
Thoughts captured: {n_thoughts}.
Top decision: {top_decision}.
```
Maximum 5 lines. `top_decision` = highest-priority/most recent decision. Skip lines that are zero except the first.

### 6.2 Scheduling
Local daily notification at the user's time (default 21:00); tapping opens a Summary screen with the same text plus quick links. Content is generated at fire time from the DB (compute a fresh summary when the app opens, and pre-compute when possible). Optional "polish" with LLM/SLM must not add facts; if it fails, the template is shown.

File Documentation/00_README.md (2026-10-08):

# Krypton v2 — Documentation Pack (Start Here)

**Project:** Krypton v2 — Meeting Intelligence Locket + Flutter App
**Hackathon PS 04:** Meeting Notes → Semantically-Zoned Minutes with Action Extraction (24 hours)
**Base:** OpenPendant repo (Flutter app + nRF firmware), XIAO nRF52840 only (no battery)

## 1. What we are building (30-second version)
A Flutter app that records a meeting from **either the phone mic or the locket (BLE)**, transcribes it with open-source Whisper, identifies speakers from enrolled voice samples, uses an LLM to split the transcript into **discussion / decision / action zones**, extracts decisions and actions with owners and deadlines, schedules **hardcoded (rule-based) reminders**, prepares **email drafts that only send after explicit human approval**, remembers every meeting for Q&A recap (cloud LLM, local-server LLM, or on-device small language model), and ends the day with a short closing summary.

## 2. Document index (read in this order)
| # | File | Purpose | Who reads it |
|---|---|---|---|
| 00 | `00_README.md` | Index, locked decisions, repo layout | Everyone |
| 01 | `01_PRD.md` | Product requirements, user stories, acceptance criteria | Everyone, esp. presenter |
| 02 | `02_SYSTEM_ARCHITECTURE.md` | Components, data flows, deployment tiers, failure modes | Tech lead |
| 03 | `03_TECH_ARCHITECTURE.md` | Stack, packages, schemas, API contracts, folder layout | All devs |
| 04 | `04_ROADMAP.md` | Phases P0–P11, tracks, gates, cut lines, hour-by-hour | Team lead |
| 05 | `05_FLUTTER_APP_GUIDE.md` | Step-by-step changes to the OpenPendant app (phone + locket capture) | App dev |
| 06 | `06_AI_PIPELINE_SPEC.md` | ASR, diarization, speaker ID, zoning prompts, SLM, RAG, eval | AI/backend dev |
| 07 | `07_REMINDERS_AND_EMAIL_SPEC.md` | Rule-based reminder engine + human-approved email drafts | App dev + backend |
| 08 | `08_VIBE_CODING_PLAYBOOK.md` | `AGENTS.md` rules file + a ready prompt for every phase | Everyone using AI coding tools |
| 09 | `09_TEST_DEMO_PITCH.md` | Test plan, eval, demo script, backup plan, judge Q&A | Presenter + QA |

## 3. Locked decisions (do not re-debate during the hackathon)
| ID | Decision | Reason |
|----|---|---|
| D1 | Keep the OpenPendant Flutter app; modify, do not rewrite | App, BLE, and Opus path already work |
| D2 | One `AudioSource` interface with two implementations: `PhoneMicSource`, `LocketBleSource` | Both inputs feed the same pipeline; BLE trouble never blocks the demo |
| D3 | Audio contract: **16 kHz, mono, PCM16, WAV** | Whisper + speaker models expect it |
| D4 | **Contract-first**: JSON schema in `/contracts` is written before any code | Vibe-coded modules must plug together |
| D5 | **LLM proposes, rules decide**: the LLM extracts tasks/deadlines/priority; reminder times come from deterministic code | Reliability, offline, explainability |
| D6 | **Human-final for email**: the app can create drafts but has no code path that sends without a user tap on a confirmation screen | Safety and trust |
| D7 | Three inference tiers: **A Cloud**, **B Local server (laptop + Ollama)**, **C On-device SLM** | Offline story with a safe fallback chain |
| D8 | Zoning is expressed as **utterance index ranges**, never free text spans | Prevents hallucinated quotes, makes validation trivial |
| D9 | The on-device SLM summarizes **structured minutes**, not raw transcripts | Small models are reliable on short structured input |
| D10 | App is **local-first** (SQLite + FTS5); server is a processing/memory booster | Works offline, simple sync |
| D11 | Calendar and email use OS intents / drafts first; direct APIs are an upgrade | No OAuth risk in the 24 hours |

## 4. Repo layout
```
krypton-v2/
├─ AGENTS.md                  # rules for AI coding tools (from file 08)
├─ docs/                      # this documentation pack
├─ contracts/                 # JSON Schemas + OpenAPI (source of truth)
│  ├─ minutes.schema.json
│  ├─ openapi.yaml
│  └─ fixtures/               # sample transcripts + golden outputs
├─ app/                       # Flutter app (forked from OpenPendant)
├─ backend/                   # FastAPI service
│  ├─ app/{api,pipeline,llm,speakers,memory,jobs}/
│  └─ tests/
├─ firmware/                  # XIAO nRF firmware (unchanged unless needed)
├─ eval/                      # eval scripts + synthetic meetings
└─ samples/                   # audio clips (AMI, TTS-generated)
```

## 5. Definition of "demo-ready"
1. Record on phone **and** on locket → minutes appear in the zone viewer.
2. Upload of a sample file works as a fallback.
3. Speakers are named from enrolled samples.
4. An action produces a notification on the phone at a rule-computed time.
5. An email draft opens for review and nothing sends without approval.
6. "What did we decide about X?" returns a cited answer.
7. A backup video of all of the above exists.

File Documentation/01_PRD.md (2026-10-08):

# 01 — Product Requirements Document (PRD)

**Product:** Krypton v2 · **Version:** 0.1 (hackathon build) · **Owner:** VENOM (Ayush) · **Status:** Draft for build

## 1. Problem
Chronological transcripts bury decisions and actions. Restructuring a meeting manually takes 20–30 minutes. Action items lose owners and deadlines, and follow-up emails and reminders are forgotten.

## 2. Vision and goals
**Vision:** Walk out of a meeting with the minutes, owners, deadlines and reminders already done.

| Goal | Measure |
|---|---|
| G1 Satisfy PS 04 exactly | Upload/record → zone-highlighted viewer → minutes with decisions + actions table |
| G2 Capture anywhere | Same result from phone mic, locket, or file upload |
| G3 Trustworthy automation | Every external side effect (email, calendar) needs user approval; reminders are deterministic |
| G4 Works with weak connectivity | Reminders, search and recap work offline; AI degrades gracefully across 3 tiers |
| G5 Memorable demo | Live locket recording to reminder on a phone in under 3 minutes |

## 3. Non-goals (this release)
Real-time live transcription UI, multi-language beyond English/Hinglish best-effort, team accounts/cloud sync, iOS parity, battery/enclosure design, auto-sending any email.

## 4. Personas
1. **Aarav, startup founder:** many short meetings, forgets follow-ups, wants minutes and drafts with no effort.
2. **Meera, project manager:** needs owners and deadlines per action, searchable history.
3. **Rohan, student team lead:** wants thoughts/ideas captured and a short daily wrap-up.

## 5. Feature list and priority
| ID | Feature | Priority | Tier |
|----|---|---|---|
| F1 | Record via phone mic | P0 | Core |
| F2 | Record via locket (BLE) | P0 | Core |
| F3 | Upload audio or transcript | P0 | Core |
| F4 | Whisper transcription | P0 | Core |
| F5 | LLM zoning into discussion/decision/action | P0 | Core |
| F6 | Zone-highlighted viewer | P0 | Core |
| F7 | Minutes: summary, decisions section, actions table | P0 | Core |
| F8 | Speaker enrollment, test sample, identification | P1 | Diff |
| F9 | Rule-based reminders (before deadlines) | P1 | Diff |
| F10 | Email drafts with human approval | P1 | Diff |
| F11 | Calendar event creation (user-confirmed) | P1 | Diff |
| F12 | Meeting memory search + recap Q&A | P1 | Diff |
| F13 | Offline recap with small language model | P2 | Stretch |
| F14 | Thoughts: capture, auto-recap, research, brainstorm | P2 | Stretch |
| F15 | Daily closing summary | P2 | Stretch |
| F16 | Important names / MoM vault | P2 | Stretch |

## 6. User stories and acceptance criteria

**US-01 Record with the phone (F1)**
As a user, I tap Record and choose "Phone", so I can capture without the locket.
- *Given* mic permission granted, *when* I tap Record, *then* a timer and level meter run and a WAV is saved when I stop.
- A foreground notification keeps recording when the screen is off (Android).

**US-02 Record with the locket (F2)**
- *Given* the locket is powered and in range, *when* I choose "Locket", *then* the app connects, shows signal/packet health, and records.
- *If* the locket disconnects, *then* the app shows a warning, keeps the partial audio, and offers "Continue on phone".

**US-03 Upload (F3)**
- *Given* a .wav/.mp3/.m4a or .txt/.vtt transcript, *when* uploaded, *then* it enters the same pipeline as a recording.

**US-04 Zone viewer (F5, F6)**
- Transcript lines are colour-coded: blue = discussion, green = decision, orange = action.
- Tapping a decision/action scrolls to and highlights its source lines. A legend filters zones.
- Each zone block shows a one-line summary and speaker chips.

**US-05 Minutes (F7)**
- Minutes show: title, date, duration, attendees, summary (≤ 6 lines), Decisions section, Actions table (task, owner, deadline, priority, status, source link).
- Cells are editable; edits persist and re-trigger reminder scheduling.
- Export to Markdown and PDF.

**US-06 Speakers (F8)**
- I can enroll a person with a 10–20 s sample and name them.
- "Test sample" records ~5 s and shows the best match with a confidence score.
- In a meeting, matched speakers show their names; unmatched show "Speaker N" and can be named afterwards (offering to enroll).

**US-07 Reminders (F9)**
- Each action with a deadline gets reminders computed by the rule table (file 07).
- *Given* airplane mode, *then* reminders still fire.
- Actions without deadlines show "Needs deadline" and are included in the daily summary.

**US-08 Email drafts with approval (F10)**
- For an action, I tap "Draft email". A draft appears with To/Subject/Body, all editable.
- The only way to send is the **Review & Send** screen with an explicit "Send" confirmation. Closing the screen leaves the draft unsent.
- Recipients must be confirmed by me; unresolved names stay blank.

**US-09 Calendar (F11)**
- "Add to calendar" opens the native calendar insert screen prefilled; the user taps Save.

**US-10 Memory and recap (F12)**
- I ask "What did we decide about pricing?" and get an answer with meeting name and timestamp citations.
- Filters: by meeting, person, zone, date range. Works over local full-text search when offline.

**US-11 Offline recap (F13)**
- With no internet and the SLM model downloaded, "Recap" of a processed meeting produces a short summary within ~30 s on a mid-range phone.

**US-12 Thoughts (F14)**
- Saying "thought: ..." in a recording, or pressing the Thought button, saves a thought with an auto-recap.
- Online: "Research this" adds a sourced summary. "Brainstorm" opens a chat seeded with the thought.

**US-13 Daily closing (F15)**
- At a set time (default 21:00) a notification summarises: meetings, decisions, actions created, due tomorrow, overdue, thoughts. Maximum 5 lines.

## 7. Non-functional requirements
| Area | Requirement |
|---|---|
| Latency | 10 min audio → minutes in ≤ 2 min (Tier A, GPU or fast CPU `small` model); 3-min demo clip ≤ 45 s |
| Accuracy (targets) | Action recall ≥ 80%, owner accuracy ≥ 70% on synthetic set (see file 09) |
| Reliability | App never loses a recording: audio is written to disk continuously |
| Privacy | Consent prompt before each recording; recording indicator; delete-meeting wipes audio, transcript, embeddings |
| Safety | No outbound email or calendar write without user action |
| Offline | Record, view, search, remind, and daily summary work with no network |
| Security | No API keys in the app; the app talks only to our backend; backend keys in env |
| Usability | Record start within 2 taps from the home screen |

## 8. Success metrics (for the pitch)
Time from stop → minutes; action recall/owner accuracy on test set; number of manual steps saved (from ~25 min to ~1 min review); reminder correctness (100% of rule test cases).

## 9. Risks
| Risk | Mitigation |
|---|---|
| BLE instability | Phone mic source and upload fallback; pre-recorded locket clip |
| Weak speaker ID in noisy rooms | Show confidence, allow rename, use enrollment of 15–20 s |
| SLM quality | Restrict to recap over structured minutes; always keep Tier A/B fallback |
| Scope creep | Cut lines in file 04; freeze at hour 21 |
| Repo surprises (auth, Firebase, old backend) | Audit in P0, stub out dependencies |

## 10. Release criteria
All P0 stories pass; at least three P1 stories pass; backup demo video recorded; every external side effect is gated by explicit user confirmation.

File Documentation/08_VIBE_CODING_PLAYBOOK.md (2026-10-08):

# 08 — Vibe Coding Playbook

How to build this with AI coding tools (Claude Code, Cursor, Copilot, etc.) without the codebase turning into soup.

## 1. Working agreement
1. **Docs are the source of truth.** Paste the relevant doc section into each prompt; don't rely on the tool "remembering".
2. **Contracts first.** Schema and API change only by editing `contracts/` first, then regenerating models.
3. **One phase = one branch = one PR-sized change.** Merge only when the phase exit criteria pass.
4. **Small prompts, runnable output.** Every prompt ends with "and show me how to run/test it".
5. **Test the risky logic by hand-written tests**, not AI vibes: reminder rules, draft approval gate, zoning validator.
6. **Pin working states:** `git tag gate-G3` etc. Roll back instead of debugging for more than 20 minutes.
7. **Humans review:** security-sensitive code (send gate, permissions) must be read by a person.

## 2. `AGENTS.md` (put in repo root; also usable as `.cursorrules` / `CLAUDE.md`)
```markdown
# Krypton v2 — Rules for AI coding agents

## Project
Flutter app (app/) + FastAPI backend (backend/) for meeting minutes with zones (discussion/decision/action).
Read docs/ before large changes: 02 system arch, 03 tech arch, 06 AI spec, 07 reminders+email.

## Hard rules
- Never add code that sends an email or creates a calendar event without an explicit user confirmation UI step. Email send path requires DraftState.approved with a fresh approval token.
- Never put API keys in the app. Secrets only in backend/.env.
- Audio contract: 16 kHz, mono, PCM16, WAV. Do not change.
- Contracts live in contracts/. If you need a new field, edit the schema first and update both sides.
- Reminder times come only from domain/reminder_rules.dart (pure function). Do not let an LLM choose notification times.
- LLM output must be validated with Pydantic; never trust raw model text.
- Reference transcript evidence by utterance index, not by quoted text.
- Keep the existing OpenPendant BLE code working; wrap it, don't rewrite it.

## Style
- Dart: null-safe, small widgets, no business logic in widgets, domain/ has no Flutter imports.
- Python: type hints, Pydantic v2, async endpoints, no global state except config.
- Add or update tests for any change in domain/ (Dart) or pipeline/ (Python).
- Prefer simple and boring over clever. No new dependencies without a one-line reason in the PR description.

## Workflow
1. Restate the task and list files you will touch.
2. Make the smallest change that satisfies the exit criteria.
3. Run tests/analyzer: `flutter analyze && flutter test`, `pytest -q`.
4. Summarize what changed and how to verify manually.

## Don't
- Don't delete existing files unless asked. Don't reformat unrelated code. Don't upgrade Flutter/major packages. Don't add telemetry.
```

## 3. Standard prompt template
```
Context: Krypton v2 (see AGENTS.md). We are in Phase {N}: {name}.
Goal: {one sentence}
Relevant spec: {paste the section from the docs}
Files to create/modify: {list}
Constraints: {2–4 bullets, e.g., pure Dart, no new deps}
Acceptance: {exit criteria from file 04}
Please: 1) list your plan, 2) implement, 3) add tests, 4) tell me exact commands to run and what I should see.
```

## 4. Phase prompts (copy, adapt, run)

### P0 — Audit
```
Audit the Flutter app in app/ for how BLE audio from the locket becomes playable audio. Find: BLE service/characteristic UUIDs, codec handling (Opus), where audio is stored, any Firebase/auth/backend dependencies, state management approach. Output docs/audit.md with file paths and a 5-line explanation of the audio flow. Also list what must be stubbed to run without login. Do not change code.
```
```
Create contracts/minutes.schema.json from the schema in docs/06_AI_PIPELINE_SPEC.md §2, and three fixtures in contracts/fixtures/ (transcript.txt + expected.json) for: a product planning meeting, a standup, a client call. Make the fixtures realistic with clear decisions, actions, owners and relative deadlines.
```

### P1 — AI core (text → minutes)
```
In backend/, implement: llm/base.py (LLMClient.generate_json), llm/claude_client.py, llm/schemas.py (Pydantic models matching contracts/minutes.schema.json), pipeline/zone.py and pipeline/extract.py using the prompt in docs/06 §4, and pipeline/validate.py implementing §4 validation + repair (coverage, referential integrity, date sanity, heuristic fallback). Add eval/run_eval.py that runs all fixtures and prints coverage validity, action recall, owner accuracy. Add pytest tests for the validator with bad inputs (gaps, overlaps, missing segment ids).
```

### P2 — ASR + API
```
Add pipeline/asr.py using faster-whisper (model from env, word timestamps, VAD) and pipeline/ingest.py (ffmpeg normalize to 16k mono WAV). Implement FastAPI endpoints per docs/03 §5: /v1/health, POST /v1/meetings (multipart audio or JSON transcript), GET /v1/jobs/{id}, GET /v1/meetings, GET /v1/meetings/{id}. Use a job table in SQLite and BackgroundTasks with stages ingest→asr→zone→extract→done and progress. Provide curl examples and a sample audio test.
```

### P3 — Flutter capture
```
In app/, add lib/audio/{audio_source,phone_mic_source,recording_session,wav_writer}.dart per docs/05 §4–5. Use the `record` package streaming PCM16 16kHz mono. RecordingSession writes the WAV continuously, exposes elapsed/level/state, and finalizes headers on stop. Add a unit test with a fake AudioSource producing 3 seconds of sine wave and verify a valid WAV. Then add a Record screen with timer, level meter, consent banner, and stop → create a meetings row in drift.
```
```
Add drift tables (meetings, utterances, segments, decisions, actions, reminders, email_drafts, speakers, thoughts, chunks_fts) per docs/03 §4.1 and repositories. Add UploadQueue with dio retry/backoff that posts meetings to /v1/meetings, polls /v1/jobs/{id}, then stores the minutes JSON into the tables. Show status chips on the meetings list.
```

### P4 — Viewer + minutes
```
Build the Meeting detail screen with two tabs. Tab 1 Zone viewer per docs/05 §10: utterances grouped by segment with zone colour + icon + label, speaker chips, legend filter, search. Tab 2 Minutes: summary, Decisions list, Actions table (editable). Tapping a decision/action scrolls to and highlights the source utterance. Load from contracts/fixtures/*/expected.json when offline-dev flag is on.
```

### P5 — Locket source
```
Using the existing BLE/Opus code found in docs/audit.md, create lib/audio/locket_ble_source.dart implementing AudioSource without changing existing behaviour. Emit PCM16 16kHz mono. Add health stream (connected, rssi, dropped frames, last packet time), reconnect with backoff, and a UI source selector on Home (Phone | Locket | Auto) with a pairing sheet. If the locket disconnects, keep the WAV and show a banner with "Continue on phone".
```

### P6 — Reminders
```
Implement lib/domain/reminder_rules.dart exactly per docs/07 §1 (pure Dart, injected `now`) plus tests covering the 9 scenarios in §1.5. Then implement ReminderScheduler using flutter_local_notifications + timezone with actions Done/Snooze, re-sync on app start, and permission handling for Android 13+/exact alarms. Add a debug button "Schedule test reminder in 2 minutes".
```

### P7 — Email + calendar
```
Implement lib/domain/draft_state_machine.dart and the Review & Send flow per docs/07 §3. Enforce the 7 invariants with unit tests (sendHandoff throws unless APPROVED with a fresh single-use token minted by ConfirmSendDialog; edit resets approval). Backend: POST /v1/actions/{id}/draft-email returning subject/body only. Handoff via mailto/Android intent. Add "Add to calendar" using add_2_calendar.
```

### P8 — Speakers
```
Backend: speakers/embeddings.py (SpeechBrain ECAPA), endpoints /v1/speakers/enroll, /test, list; pipeline/diarize.py (pyannote 3.1) and pipeline/speaker_match.py per docs/06 §1 and §6 with calibratable threshold in config. App: Speakers screen with enroll (record 15 s, show quality) and Test sample (record 5 s, show best match + score), and rename "Speaker N" inside a meeting.
```

### P9 — Memory
```
Backend: memory/{store,retrieve,answer}.py with Chroma + bge-small, chunking per docs/06 §7, POST /v1/ask returning answer + citations (meeting_id, start_s). App: Ask screen with filters and tappable citations that open the meeting at that timestamp. Also fill the local FTS5 table after each meeting and use it when offline.
```

### P10 — Offline tiers
```
Backend: llm/ollama_client.py implementing LLMClient; LLM_PROVIDER switch; lower temperature and stricter JSON retry. App: InferenceRouter (Auto/A/B/C) with health checks and a visible tier badge. Then, optional: local_slm.dart that downloads a Q4 1.5B model on demand and generates a 4-line recap from structured minutes with a 60s timeout and an extractive fallback (docs/06 §8). Mark as Experimental in UI.
```

### P11 — Thoughts + daily summary
```
Add Thoughts: quick-capture button (voice or text), backend /v1/thoughts (recap+tags), /research (Tavily + sourced summary), /brainstorm chat. Detect trigger phrases in utterances per docs/06 §9. Add DailySummary template builder (pure Dart, per docs/07 §6) and a daily local notification at the configured time.
```

### P12 — Polish
```
Create a QA checklist run-through: fix crashes, empty states, loading states, and error messages for: no network, mic denied, BLE off, backend down, invalid JSON. Add a demo mode that seeds three prepared meetings and enrolled speakers. Prepare release APK build instructions.
```

## 5. Debugging prompts
```
Here is the error and the relevant file. Explain the root cause in two sentences, then give the smallest fix. Do not refactor.
```
```
This works on the emulator but fails on the physical phone. List the three most likely causes related to permissions, BLE, or audio format, and the log lines that would confirm each.
```
```
The LLM returned invalid JSON for this transcript (paste). Improve the prompt or validator minimally; show a failing test first.
```

## 6. Context hygiene
- Start a fresh chat per phase; paste AGENTS.md + the doc excerpt.
- Keep a `docs/STATE.md` updated at each gate: what works, what's broken, next 3 tasks. Paste it into new sessions.
- Don't let the tool "improve" architecture mid-hackathon.

## 7. Team workflow
- Branches: `feat/p3-capture`, `feat/p1-ai-core`… Merge to `main` only at green gates.
- Two people must not edit the same file; the schema and API are the only shared surfaces.
- Everyone pulls `main` every hour; demo build is always built from `main`.
- Daily-driver commands: `flutter analyze && flutter test`, `pytest -q`, `python eval/run_eval.py`.

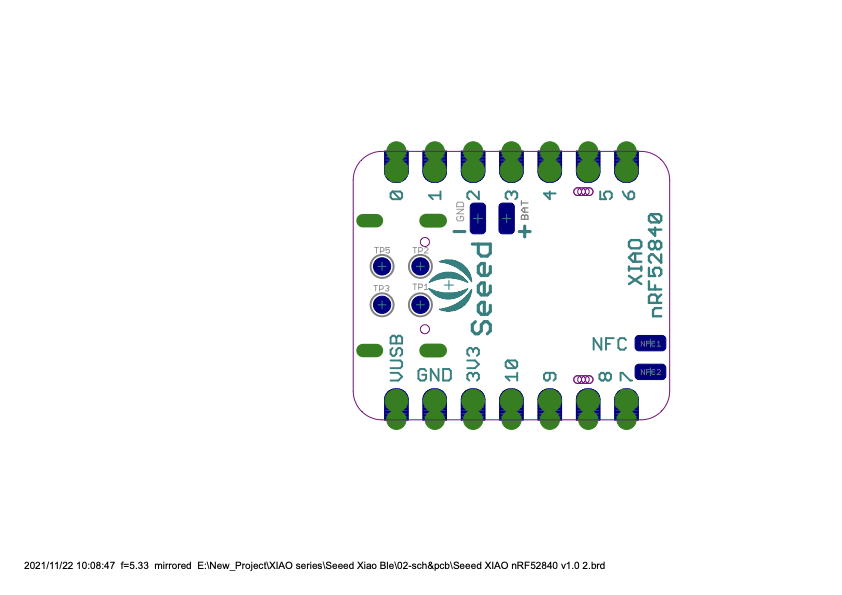
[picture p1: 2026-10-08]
docs/cad/xiao_bottom_silkscreen.png

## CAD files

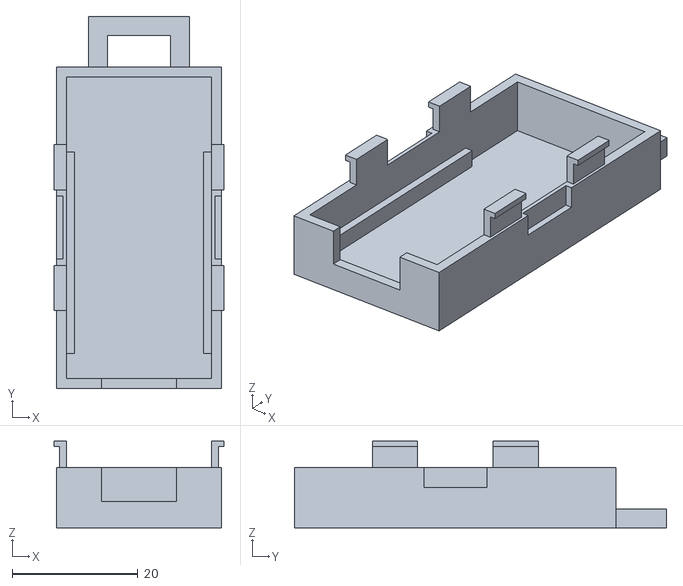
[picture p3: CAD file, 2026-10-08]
docs/cad/pendant_case_back.stl
27.0 x 59.2 x 13.8

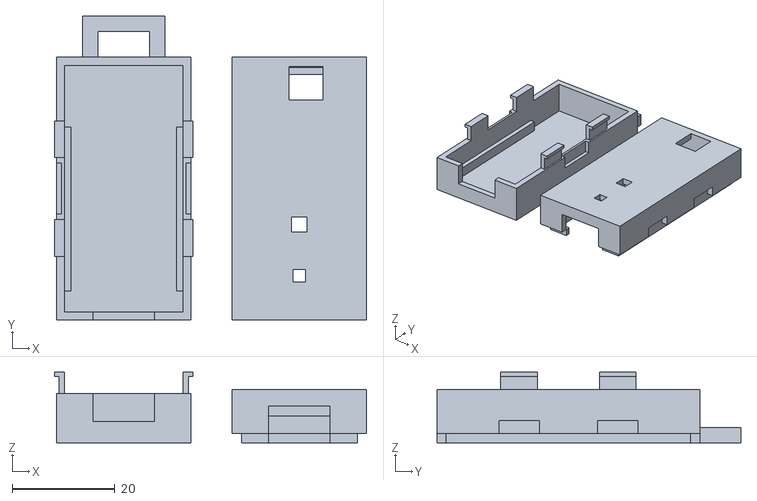
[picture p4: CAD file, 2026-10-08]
docs/cad/pendant_case_print.stl
60.8 x 59.2 x 13.8

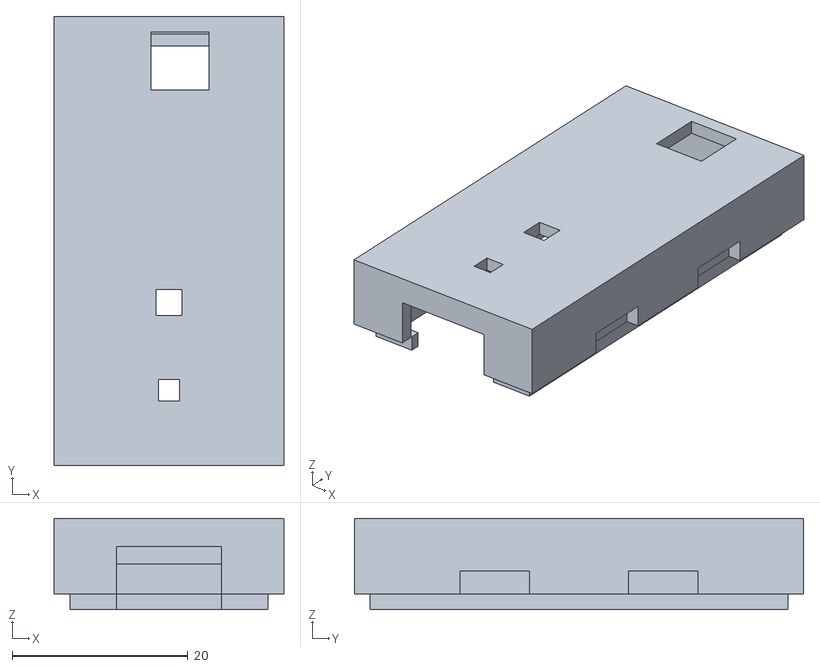
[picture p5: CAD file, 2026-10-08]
docs/cad/pendant_case_front.stl
26.2 x 51.2 x 10.4

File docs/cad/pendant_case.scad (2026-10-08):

// OpenPendant clamshell — PETG, 0.2 mm layers, 3 walls.
// USB-C window on the bottom seam. No SD slot: open the lid to reach the card.
// Units: millimetres.

inner_w = 23;
inner_h = 48;
inner_d_back = 8.0;
inner_d_front = 7.0;
wall = 1.6;
usb_w = 12.0;
usb_h = 5.4;
mic_y = 17;
mic_r = 1.5;
led_y = 7;
led_r = 1.2;
btn_y = 44.5;
btn_r = 3.3;
bail_h = 8;
bail_t = 3;
$fn = 32;

outer_w = inner_w + 2 * wall;
outer_h = inner_h + 2 * wall;

module usb_cut(z, h) {
  translate([-usb_w / 2, -1, z]) cube([usb_w, wall + 2, h]);
}

module back() {
  difference() {
    union() {
      difference() {
        cube([outer_w, outer_h, inner_d_back + wall], center = false);
        translate([wall, wall, wall])
          cube([inner_w, inner_h, inner_d_back + 1]);
      }
      // cord bail
      translate([outer_w / 2 - 8, outer_h, 0]) cube([3, bail_h, bail_t]);
      translate([outer_w / 2 + 5, outer_h, 0]) cube([3, bail_h, bail_t]);
      translate([outer_w / 2 - 8, outer_h + bail_h - bail_t, 0])
        cube([16, bail_t, bail_t]);
    }
    usb_cut(inner_d_back + wall - usb_h, usb_h + 1);
    // fingernail grooves
    translate([-0.1, outer_h / 2 - 7, inner_d_back + wall - 3.4])
      cube([1.3, 14, 3.6]);
    translate([outer_w - 1.2, outer_h / 2 - 7, inner_d_back + wall - 3.4])
      cube([1.3, 14, 3.6]);
  }
}

module front() {
  difference() {
    cube([outer_w, outer_h, inner_d_front + wall], center = false);
    translate([wall, wall, -1]) cube([inner_w, inner_h, inner_d_front + 1]);
    usb_cut(-1, usb_h + 1);
    translate([outer_w / 2, wall + mic_y, inner_d_front])
      cylinder(h = wall + 2, r = mic_r);
    translate([outer_w / 2, wall + led_y, inner_d_front])
      cylinder(h = wall + 2, r = led_r);
    translate([outer_w / 2 + 1.27, wall + btn_y, inner_d_front])
      cylinder(h = wall + 2, r = btn_r);
  }
}

// Preview both; export each module separately for print.
translate([-outer_w - 4, 0, 0]) back();
front();

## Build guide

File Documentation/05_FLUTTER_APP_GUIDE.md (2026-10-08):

# 05 — Flutter App Guide: Adding Phone-Mic and Locket Capture

Goal: one app, two inputs (phone mic, locket), one pipeline. Do the steps in order; each ends with a check.

## 1. Setup
1. Clone the OpenPendant repo into `app/`, run `flutter doctor`, pin the Flutter version the repo uses (check `.fvm`, `pubspec.yaml` `environment`).
2. Build and run on a **physical Android phone** (BLE and mic do not work properly on emulators).
3. Make a branch `feat/dual-capture`. Commit after every step.

## 2. Audit the existing app (write findings in `docs/audit.md`)
Run these searches in the repo and note file paths:
| Question | Search hint |
|---|---|
| Where is BLE scanning/connecting? | `flutter_blue_plus`, `FlutterBluePlus`, `BluetoothDevice`, `connect(` |
| Service/characteristic UUIDs? | `Guid(`, `serviceUuid`, `19b10000` (UUID prefix common in Omi-derived firmware; **verify against your firmware**) |
| Codec handling? | `opus`, `codec`, `decode`, `pcm` |
| Where is audio stored/streamed? | `wav`, `File(`, `socket`, `websocket`, `stream` |
| Backend/auth dependencies? | `firebase`, `auth`, `http.post`, `api_base_url`, `.env` |
| State management? | `Provider`, `ChangeNotifier`, `Riverpod`, `Bloc` |
Deliverable: a list of the 5–10 files you will touch, and a list of external services to stub out.
**Check:** you can explain, in 5 lines, how a BLE audio packet becomes playable audio today.

## 3. Strip or stub dependencies
- If the app requires login/Firebase/Omi cloud on startup, add a `DEV_MODE` flag that skips auth and removes cloud calls. Do not delete code you are unsure about; gate it.
- Point all network calls to a single `ApiClient` with base URL from settings.
**Check:** app launches to your own Home screen with no login.

## 4. Define the audio contract and abstraction
Create `lib/audio/audio_source.dart` (interface in file 03). Contract: PCM16, 16 kHz, mono, little-endian; the source handles resampling/decoding.
Create `lib/audio/recording_session.dart`:
- Takes an `AudioSource`, opens a `WavWriter`, appends bytes as they arrive (**write to disk continuously**, not at the end).
- Exposes `elapsed`, `level` (RMS), `state` (idle/recording/paused/stopped), `sourceHealth`.
- On stop: patches WAV header sizes, creates the meeting row (`status=recorded`).
- On app restart: scans for unfinalized WAVs and offers recovery.
**Check:** unit test with a fake source writing 3 s of sine wave produces a valid, playable WAV.

## 5. PhoneMicSource
- Package: `record`. Use the streaming API with `encoder: pcm16bits`, `sampleRate: 16000`, `numChannels: 1`.
- Permissions: request `RECORD_AUDIO` at first use; explain why.
- Android: start `flutter_foreground_task` with a microphone foreground-service type so recording survives screen-off.
- Consider disabling aggressive noise suppression/AGC if audio sounds pumped (Whisper prefers natural audio).
**Check:** 30 s recording plays back clean; screen-off recording works.

## 6. LocketBleSource (wrap, don't rewrite)
1. Move the repo's existing "connect + subscribe + decode" logic behind `LocketBleSource implements AudioSource`.
2. Output: decoded PCM from the Opus frames. If the repo decodes to 16 kHz mono already, pass through; otherwise resample.
3. Health: emit `connected`, `rssi`, `droppedFrames` (detect gaps via packet index if the firmware sends one), `lastPacketAt`.
4. Reconnect: exponential backoff up to 10 s, keep the same `RecordingSession` open; insert silence for gaps up to 2 s, otherwise mark a gap.
5. Foreground service for BLE as well; request `BLUETOOTH_SCAN` / `BLUETOOTH_CONNECT` (Android 12+).
**Check:** record 60 s from the locket, play the WAV, speech is intelligible; unplug the locket mid-recording and the app shows the warning and keeps the audio.

## 7. Source selector and Record screen
- Home: big Record button plus a segmented control **Phone | Locket | Auto** (Auto = locket if connected else phone).
- Record screen: timer, level meter, source badge, health row (BLE signal, dropped frames), pause/stop, **consent banner**, bookmark button ("mark this moment").
- Locket pairing sheet: scan, pick device, remember last device.
**Check:** switching source before recording works; the same pipeline produces a meeting row for both.

## 8. Local database (drift)
Implement tables from file 03 (start with `meetings`, `utterances`, `segments`, `actions`; add the rest as phases need them). Generate DAOs and repositories. Add FTS5 `chunks_fts`.
**Check:** insert a fixture minutes JSON and render it without network.

## 9. Upload + job polling
- `UploadQueue`: stores pending uploads, retries with backoff, resumes after restart, one at a time.
- `POST /v1/meetings` (multipart) → poll `/v1/jobs/{id}` every 2 s → on `ready` fetch minutes → write to DB → index FTS5 → schedule reminders.
- Show per-meeting status chips: Recorded · Uploading · Processing (stage) · Ready · Failed (Retry).
**Check:** airplane mode → recording saved as "Recorded"; reconnect → auto uploads.

## 10. Screens (build in this order)
1. Home (record, recent meetings, today's actions) 2. Record 3. Meetings list 4. **Meeting detail: Zone viewer** 5. **Minutes** 6. Actions 7. Speakers (enroll, test) 8. Drafts + Review & Send 9. Ask 10. Thoughts 11. Settings (server URL, tier, quiet hours, daily summary time, model download).

### Zone viewer spec
- List of utterance rows grouped into segment blocks; block header shows zone icon, one-line summary, time range, speaker chips.
- Colours (use theme tokens): discussion = blue, decision = green, action = orange. Never rely on colour alone: also show an icon and label.
- Tap decision/action chip in Minutes → `scrollToUtterance(idx)` with a 2 s highlight.
- Legend toggles filter zones. Search within transcript.

## 11. Manifest and permissions (Android)
`RECORD_AUDIO`, `BLUETOOTH_SCAN`, `BLUETOOTH_CONNECT`, `POST_NOTIFICATIONS`, `SCHEDULE_EXACT_ALARM` (or `USE_EXACT_ALARM` if eligible), `RECEIVE_BOOT_COMPLETED`, `FOREGROUND_SERVICE`, `FOREGROUND_SERVICE_MICROPHONE`, `FOREGROUND_SERVICE_CONNECTED_DEVICE`, `INTERNET`. Declare queries for mail/calendar intents. iOS parity is out of scope.

## 12. Pitfalls checklist
- BLE MTU/throughput: request a larger MTU; log packet rates.
- Opus frame size mismatches cause "robot" audio; check sample rate and frame duration.
- Doze mode can delay notifications; use exact alarms and tell the user to disable battery optimization for the demo phone.
- Large WAVs: 16 kHz mono PCM16 ≈ 1.9 MB/min; compress to FLAC/Opus for upload only if bandwidth is a problem.
- Keep the old OpenPendant features that still work; hide what you do not need behind a settings flag.
- Do not request more permissions than needed on first launch; ask in context.

## 13. Definition of done (app dual capture)
Both sources produce identical meeting rows and WAV format; consent shown; recording survives screen-off; interrupted recording recoverable; upload queue survives restarts.

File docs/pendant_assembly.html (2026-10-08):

OpenPendant · hardware

# Compact pendant assembly

This matches the board in your photos: USB at the bottom, XIAO, then the microSD module on the same face, spare holes at the top for the button. Solder every digital joint first. The LiPo goes on the back of the strip last, through the BAT window you already cut. Red to BAT+, black to BAT− — not onto the GND bus.

## Interactive CAD

Drag to orbit, scroll to zoom. Use Solder to explode the stack, Closed to check USB and the button hole, Case to judge the shell. Click a part. Needs no internet if you open the HTML from the docs/ folder.

Solder Closed Case Explode Case Labels Click a part

Click a part. Solder view is your strip: XIAO + SD on the front, LiPo exploded off the back, gold BAT pads in the window. Grey dots near USB are SWD, not battery.

LiPo last, on the back. 1S only (3.7 V). Cut the JST off the cell. Red to BAT+, black to BAT− through the window — never to the digital GND bus. Kapton every BAT joint before the pouch touches copper. SD VCC is 3V3 only. Leave XIAO 5V empty. If header pins already poke through, clip them flush on the battery side so the pack sits flat.

## Your board

USB at one short edge. XIAO then SD in a line on the world face. BAT window already cut so the LiPo can sit against the back after the jumpers are done.

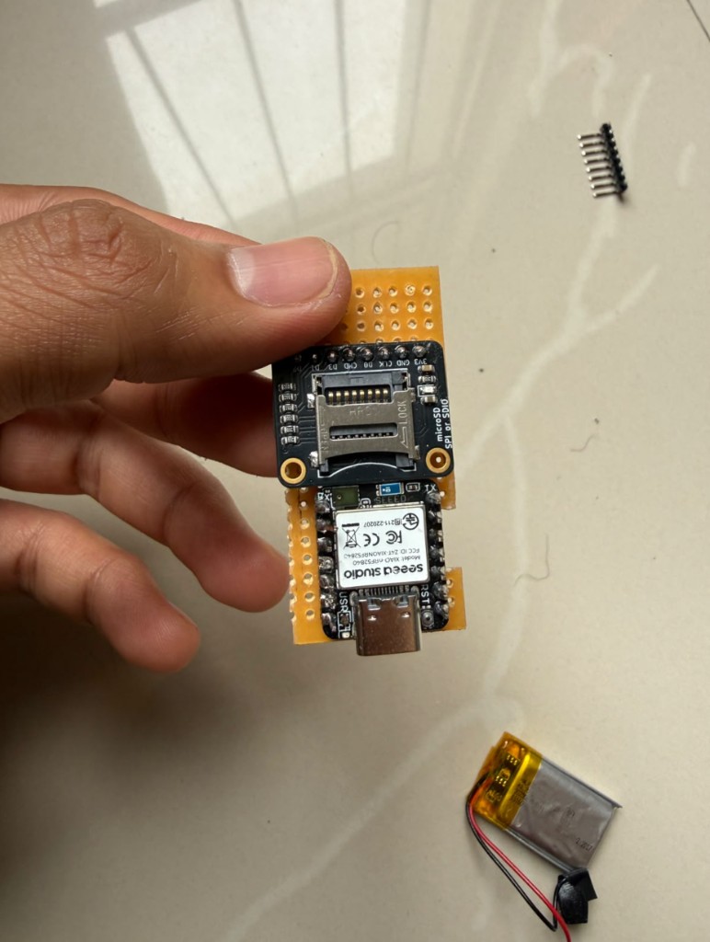
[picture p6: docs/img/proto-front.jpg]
XIAO and microSD on the front of the cut perfboard, USB at the bottom


World face. USB-C flush at the bottom. SD slot toward the top, 8-pin header facing the XIAO.

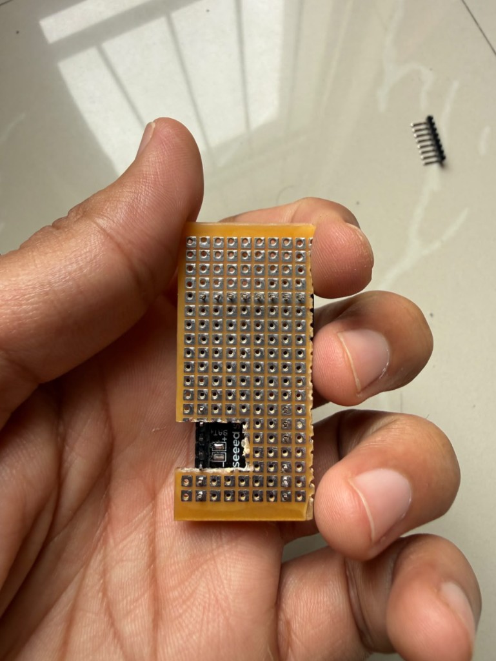
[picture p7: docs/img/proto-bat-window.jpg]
Back of the strip with a cutout showing XIAO BAT+ and BAT- pads


Back. Window shows BAT+ / BAT−. Clip header tails flush here before the cell.

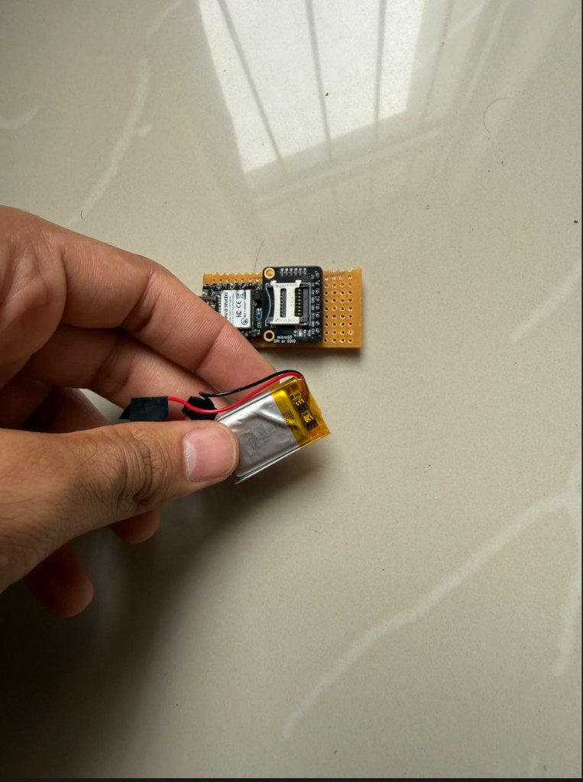
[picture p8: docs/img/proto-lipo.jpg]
LiPo held next to the strip for scale


LiPo after wiring: tape it on this back face, PCM toward the BAT window. Do not solder it yet.

## Part dimensions

The strip is about 8 × 18 holes (20 × 46 mm). That is the XIAO, a gap, the SD module, and 2–3 spare rows at the top for the button. The LiPo (20 × 30) covers the back of the XIAO after the joints are done.

Part | Size (mm) | Where
Perfboard strip | 20.3 × 45.7 × 1.6 | 8 × 18 holes. USB on the bottom edge. BAT window on the XIAO back.
XIAO nRF52840 | 21.0 × 17.5 × 3.5 | Front, USB flush at the bottom. BAT pads through the window.
microSD SPI/SDIO | ≈ 20 × 18 × 3 | Front, above the XIAO. Header faces the XIAO. Slot toward the top.
2-pin tactile | Ø6 × 5 + 1.8 plunger | Spare holes above the SD (C4 R1 / C6 R1). Plunger through the lid.
22 µF cap | ≈ Ø5 or 1206 ceramic | Across SD 3V3 and GND (adjacent pins). 16 V ceramic preferred.
WLY602030 LiPo | 30 × 20 × 6 | Back of the strip, last. PCM at the BAT window. Not on the GND bus.
Finished sandwich | ≈ 23 × 48 × 15 | Front: XIAO + SD + button. Middle: FR4. Back: LiPo only.

## Views

1 · Side

### Sandwich thickness

SD is on the front with the XIAO. Only the cell is behind the strip.

2 · Front

### World face

Same face as the photo: SD above the XIAO, USB at the bottom, button in the spare rows.

3 · Back

### Chest face

Tape the BAT joints, clip pin tails, then stick the pack on. No SD on this side.

## How this sandwich works

Digital stuff on the front of the strip. Battery on the back, after those joints are done. Shared GND is for the SD module, the button, and the 22 µF — not for the LiPo.

Layer | What lives there
World face | XIAO (mic out), SD slot, Ø6 button, USB-C at the bottom
FR4 strip | GND bus, 3V3, SPI jumpers on the copper side, 22 µF across SD 3V3/GND
Chest face | LiPo only, after every other joint. Leads through the BAT window.

Headers already on the XIAO are fine. Clip the tails flush on the battery side so the pouch sits flat.

## Connection diagram

Solder these on the back of the strip, in the gap between the XIAO and the SD header. USB at the bottom, component face toward you: D10 sits on the left (5V, GND, 3V3, then D10). D0–D6 are on the right. SD silk, left to right toward the XIAO: 3V3 GND CLK D3 CMD D0 D1 D2. Leave SD D1 and SD D2 unconnected. Button is XIAO D1. Do not use XIAO 5V.

### BAT window (you already cut this)

Back, USB at the bottom: D0–D6 and the BAT pads are on the left. The four dots near USB are SWD, not battery.

### Solder this list (front first)

From | To
SD 3V3 | XIAO 3V3 — never 5V
SD GND | XIAO GND (this is the shared digital ground)
SD CLK | D9
SD CMD (MOSI) | D8
SD D0 (MISO) | D7
SD D3 (CS) | D6
SD D1, D2 | No connect
22 µF | Across SD 3V3 and SD GND
Button NO | D1
Button COM | XIAO GND (same bus as SD GND)
LiPo red (last) | BAT+ in the window
LiPo black (last) | BAT− in the window

Meter the button: open until pressed, then D1 shorts to GND. If swapped, swap the two button leads.

## Assembly

Digital joints first. LiPo on the back last — the order you described.

1. Confirm the strip. USB flush at the bottom. XIAO, then SD on the same face, spare holes above the SD. BAT window already shows BAT+ / BAT−. Clip any header tails flush on that back face.
2. SD to XIAO on the copper side. Short jumpers in the gap: 3V3→3V3, GND→GND, CLK→D9, CMD→D8, D0→D7, D3→D6. Leave SD D1 and SD D2 open. Leave XIAO 5V empty.
3. 22 µF. Across the SD 3V3 and GND pins (they sit next to each other). Ceramic 16 V preferred. If electrolytic, stripe to GND.
4. Button in the spare holes above the SD: NO → D1, COM → GND. Body sits on the FR4. Do not glue it into the lid.
5. Meter, still no cell. 5V open. 3V3 not shorted to GND. D1 open to GND, short when pressed. SD VCC reads 3V3, not 5V.
6. LiPo last. Cut the JST off the pack. Solder red to BAT+, black to BAT− through the window. Heat-shrink. Kapton the joints. Tape the pouch onto the back (PCM toward the window). Do not fold it.
7. Case. Strip in the lid rails, USB in the bottom window, plunger in the Ø6.6 hole, mic under its hole. Snap shut. A dab of glue at the USB shoulders after a charge-port test.
8. Power. USB first, no cell. Then cell. Then USB with cell (charges). Press the lid button.

### Wear orientation

Conversation is in front of you, so the XIAO component face (mic) points away from your chest. The LiPo is the chest pad. IMU sleep will see walking motion; that is expected. Charge without opening the case: plug USB-C into the bottom window.

## 3D-printed case

Two-piece snap clamshell sized to your strip: XIAO + SD on the front, LiPo on the back. About 26 × 59 × 18 mm closed (with bail). USB-C on the bottom. Ø6.6 hole over the button.

Closed

### Wear / charge

Plug in from below. Do not open the case to charge.

Open

### Fingernail split

Pull the lid at a side groove. Snaps are 45° so they print without support.

Side

### USB on the seam

The port sits on the XIAO, so the cut is at the lid side of the seam, not against your chest.

### Print files

File | What
pendant_case_print.stl | Both halves on one plate
pendant_case_back.stl | Chest shell + cord bail
pendant_case_front.stl | World lid: mic, LED, button holes
pendant_case.scad | Parametric source if you resize
generate_case.py | Rebuilds the STLs (Python 3, no extras)

Slicer: drop in the print plate STL. Units are millimetres.

### Case dimensions

| mm
Inner cavity | 23 × 48 × 15
Outer, closed, with bail | 26 × 59 × 18
Wall | 1.6
USB-C window | 12.0 × 5.4
Mic hole | Ø 3.0
LED hole | Ø 2.4
Button hole | Ø 6.6 (plunger through, body stays inside)
Nail grooves | 14 × 3.4 × 1.2

### Print settings

Setting | Value
Material | PETG (snaps). PLA works for a first fit.
Layer / nozzle | 0.20 mm / 0.40 mm
Walls / infill | 3 walls, 15% gyroid
Orientation | Back: chest face on the bed, cavity up. Front: lip on the bed. Bail stands up.
Supports | Off. Barbs are 45°.
Brim | Yes, 5 mm, on the front lid lip

1. Test fit the empty case. Snap together, then open from a side groove. If it is too tight, sand the lip; if it falls open, reprint with BARB = 1.0 in generate_case.py.
2. Seat the electronics. LiPo against the back floor (already taped to the strip). USB-C in the bottom window, button plunger in the Ø6.6 lid hole, mic under its hole. Do not pinch the pouch.
3. Close and charge. Snap the lid. Plug USB-C with the necklace on or off. The BQ25101 on the XIAO still charges the 1S cell. Red LED should show through the small hole.

If the USB plug does not seat, the XIAO is not flush with the strip’s bottom edge — pull it to the USB end before the joints set, and reprint only after a dry-fit in the open lid.

OpenPendant hardware note — 8×18 strip, SD on the front, LiPo on the back last. Slice docs/cad/pendant_case_print.stl. Use the 3D view above to dry-fit.

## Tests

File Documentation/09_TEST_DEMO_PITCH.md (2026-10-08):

# 09 — Test Plan, Demo Script, Pitch, Judge Q&A

## 1. Test strategy
| Layer | What | How | Owner |
|---|---|-----|---|
| Domain (Dart) | Reminder rules, draft state machine, daily summary, WAV writer | `flutter test` (written by hand, see file 07) | App dev |
| Pipeline (Python) | Validator, repair, chunk merge, date resolution | `pytest` | Backend dev |
| AI quality | Zoning, actions, owners, deadlines | `eval/run_eval.py` against golden fixtures | AI lead |
| Integration | Phone record → upload → minutes → reminders | Manual checklist on a real phone | QA |
| Hardware | Locket stream quality, reconnect, range | 3 × 5-minute soak tests | Hardware |
| Safety | No send without approval, consent shown | Unit tests + manual attempt to bypass | QA |

## 2. Test data
- **Synthetic:** 5–7 meetings generated by an LLM with a hidden answer key (decisions, actions, owners, deadlines). Include tricky cases: unassigned action, deadline stated vaguely ("sometime next week"), a decision reversed later, small talk, interruptions.
- **AMI-style:** 3 clips/transcripts for realism.
- **Audio:** record 2–3 teammates reading/acting scripts in a quiet room and in a noisy room; one clip from the locket, one from the phone, one uploaded file.
- **Speaker ID:** enrollment samples for 3 teammates + one unenrolled voice (to test false accepts).

## 3. Manual QA checklist (run at hour 21 and again at hour 23)
**Capture**
- [ ] Phone record 2 min, screen off, stop → file plays back
- [ ] Locket record 2 min → intelligible
- [ ] Locket disconnected mid-recording → warning, audio kept, continue on phone
- [ ] Upload .wav and .txt both work
- [ ] Consent banner visible

**Minutes**
- [ ] Zone viewer shows all three zones with icons and colours
- [ ] Tap a decision/action scrolls to its source
- [ ] Editing an action updates the table and reminders
- [ ] Export works

**Automation**
- [ ] Reminder fires on schedule (use a deadline 3 min away)
- [ ] Airplane mode: reminders still fire
- [ ] Draft opens, cannot send without confirm dialog; back button leaves it unsent
- [ ] Calendar insert screen opens prefilled

**Speakers & memory**
- [ ] Test sample identifies the right teammate; unenrolled voice is "unknown"
- [ ] Three prepared questions return cited answers
- [ ] Offline search works with internet off

**Offline & stretch**
- [ ] Tier B works over hotspot with the internet disabled
- [ ] SLM recap works or shows the extractive fallback
- [ ] Thought captured; daily summary notification fires

**Failure handling**
- [ ] Backend off → "Queued, will process later"
- [ ] Mic denied / BLE off → helpful messages

## 4. Demo script (≈ 3 minutes live + slides)
| Time | Action | Say |
|---|---|-----|
| 0:00 | Show locket on table, phone on Home | "This is Krypton. A meeting happens, and 60 seconds later the minutes exist." |
| 0:15 | Two teammates role-play a 30-second meeting (pre-agreed script with 1 decision, 2 actions with owners and dates) | – |
| 0:45 | Stop recording; show processing stages | "Open-source Whisper transcribes, we identify speakers, and an LLM splits the meeting into zones." |
| 1:15 | Zone viewer: blue/green/orange; tap a decision | "Decisions and actions are no longer buried." |
| 1:35 | Actions table with owners/deadlines; names matched from enrolled voices | "Owners are inferred and speakers recognized from a 15-second sample." |
| 1:55 | Tap Draft email → Review & Send → show confirm dialog, then cancel | "Nothing is ever sent without a human tap." |
| 2:10 | Reminder notification arrives (pre-scheduled 1 min out) | "Reminders are rule-based and work offline." |
| 2:25 | Ask: "What did we decide about the launch date?" | "Memory with citations." |
| 2:45 | Flip airplane mode, show offline recap (Tier B or C) | "And it works without internet." |
| 3:00 | Close on the daily summary card | "Your day, summarized in five lines." |
**Backup:** pre-recorded video of the full flow; pre-processed meetings seeded in demo mode; second phone fully charged; USB power for the locket (no battery); mobile hotspot configured for Tier B.

## 5. Pitch deck outline (10 slides, 5 minutes)
1. Title + tagline "Your meetings, already organised."
2. Problem: buried decisions, 20–30 min manual work (PS 04 numbers).
3. Solution overview: one pipeline diagram (Capture → Transcribe → Identify → Zone → Extract → Act → Remember).
4. **Core: semantic zoning screenshot** (before/after).
5. Minutes: decisions + actions table with owners/deadlines.
6. Capture anywhere: phone or locket; offline tiers.
7. Trust by design: rule-based reminders, human-approved emails, consent, local-first.
8. Tech: Flutter, FastAPI, Whisper, pyannote/SpeechBrain, Claude/Ollama/on-device SLM.
9. Results: eval table (zone accuracy, action recall, owner accuracy, latency) + time saved.
10. Roadmap + team + QR/demo.
Colour code zones identically in the app and slides. Keep text minimal; screenshots carry the story.

## 6. Judge Q&A prep
| Question | Answer |
|---|---|
| How is this different from Otter/Fireflies? | Semantic zoning with decisions/actions as first-class, wearable + phone capture, speaker enrollment, rule-based reminders, human-approved actions, offline tiers, open-source stack. |
| How accurate is it? | Show the eval table; state the test set size honestly; mention the validator and repair step and that unassigned owners are flagged. |
| What if the LLM hallucinates an action? | Evidence is referenced by utterance index, each action links to its source line, low-confidence items are flagged, and nothing external happens without approval. |
| Privacy? | Consent prompt, recording indicator, local-first storage, delete wipes audio/embeddings, keys stay on the server, optional fully local mode (Tier B/C). |
| Why rule-based reminders? | Deterministic, testable, offline; LLM only extracts deadline and priority. |
| Does the offline mode really work? | Tier B: local server with an open model, no internet. Tier C: on-device small model summarizes structured minutes; extractive fallback guarantees output. Be upfront that full zoning quality is best in Tier A/B. |
| Speaker ID in noisy rooms? | Confidence is shown, a threshold is tuned, unknown speakers stay labeled, and the user can rename and enroll. |
| Can it send emails by itself? | No, by design: drafts only, explicit confirmation required, enforced and tested in code. |
| What would you build next? | Battery + enclosure, live captions, calendar/Slack integrations, team workspaces, multilingual. |

## 7. Final-hours checklist
- [ ] Feature freeze at hour 21 (tag `freeze`)
- [ ] Release APK built from `main`, installed on two phones
- [ ] Backend running on the demo laptop with models preloaded; `.env` checked
- [ ] Demo data seeded; enrolled voices present
- [ ] Notification permission + exact alarms granted; battery optimization off
- [ ] Locket flashed, USB power tested, spare cable
- [ ] Backup video recorded and on the phone and laptop
- [ ] Slides exported to PDF; QR code works
- [ ] Rehearsed three times with a timer; roles assigned for Q&A

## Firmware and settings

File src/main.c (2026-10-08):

#include <errno.h>
#include <string.h>
#include <stdio.h>
#include <zephyr/kernel.h>
#include <zephyr/device.h>
#include <zephyr/drivers/gpio.h>
#include <zephyr/drivers/adc.h>
#include <zephyr/drivers/sensor.h>
#include <zephyr/dt-bindings/adc/nrf-saadc.h>
#include <hal/nrf_power.h>
#include <hal/nrf_pdm.h>
#include <zephyr/audio/dmic.h>
#include <zephyr/sys/printk.h>
#include <zephyr/sys/byteorder.h>
#include <zephyr/bluetooth/bluetooth.h>
#include <zephyr/bluetooth/conn.h>
#include <zephyr/bluetooth/uuid.h>
#include <zephyr/bluetooth/gatt.h>
#include <zephyr/bluetooth/hci.h>
#include <zephyr/bluetooth/att.h>

#define MAX_SAMPLE_RATE  16000
#define SAMPLE_BIT_WIDTH 16
/* One GATT notify at ATT MTU 247 (3 + 4 header + 240). Splitting a 1024-byte
 * PDM block across 5 notifies, then concatenating if a middle notify was
 * dropped, is how pendant STT became noise while the phone mic stayed fine.
 */
#define BLOCK_SIZE       240

#define DEVICE_NAME     CONFIG_BT_DEVICE_NAME
#define DEVICE_NAME_LEN (sizeof(DEVICE_NAME) - 1)

/* Custom GATT UUIDs (also listed in project_context.md) */
#define PENDANT_SVC_UUID_VAL \
	BT_UUID_128_ENCODE(0x70301101, 0x4a1b, 0x4c8d, 0x9e0f, 0xa1b2c3d4e5f6)
#define PENDANT_PCM_UUID_VAL \
	BT_UUID_128_ENCODE(0x70301102, 0x4a1b, 0x4c8d, 0x9e0f, 0xa1b2c3d4e5f6)
#define PENDANT_STATUS_UUID_VAL \
	BT_UUID_128_ENCODE(0x70301103, 0x4a1b, 0x4c8d, 0x9e0f, 0xa1b2c3d4e5f6)
#define PENDANT_CTRL_UUID_VAL \
	BT_UUID_128_ENCODE(0x70301104, 0x4a1b, 0x4c8d, 0x9e0f, 0xa1b2c3d4e5f6)

#define PCM_HDR_SIZE 4

K_MEM_SLAB_DEFINE_STATIC(rx_mem_slab, BLOCK_SIZE, 8, 4);

const struct device *mic_dev = DEVICE_DT_GET(DT_NODELABEL(dmic_dev));
const struct device *imu_dev = DEVICE_DT_GET(DT_NODELABEL(lsm6ds3tr_c));
static const struct gpio_dt_spec led = GPIO_DT_SPEC_GET(DT_ALIAS(led0), gpios);
static const struct gpio_dt_spec led_green =
	GPIO_DT_SPEC_GET(DT_ALIAS(led1), gpios);
static const struct gpio_dt_spec led_blue =
	GPIO_DT_SPEC_GET(DT_ALIAS(led2), gpios);
static const struct gpio_dt_spec user_btn =
	GPIO_DT_SPEC_GET(DT_NODELABEL(user_btn), gpios);

static const struct bt_uuid_128 pendant_svc_uuid = BT_UUID_INIT_128(PENDANT_SVC_UUID_VAL);
static const struct bt_uuid_128 pendant_pcm_uuid = BT_UUID_INIT_128(PENDANT_PCM_UUID_VAL);
static const struct bt_uuid_128 pendant_status_uuid = BT_UUID_INIT_128(PENDANT_STATUS_UUID_VAL);
static const struct bt_uuid_128 pendant_ctrl_uuid = BT_UUID_INIT_128(PENDANT_CTRL_UUID_VAL);

/* Name in the primary packet so macOS CoreBluetooth sees it (31-byte ADV
 * cannot hold both a complete name and a 128-bit UUID). UUID is in the
 * scan response.
 */
static const struct bt_data ad[] = {
	BT_DATA_BYTES(BT_DATA_FLAGS, (BT_LE_AD_GENERAL | BT_LE_AD_NO_BREDR)),
	BT_DATA(BT_DATA_NAME_COMPLETE, DEVICE_NAME, DEVICE_NAME_LEN),
};

static const struct bt_data sd[] = {
	BT_DATA_BYTES(BT_DATA_UUID128_ALL, PENDANT_SVC_UUID_VAL),
};

static volatile bool ble_ok;
static volatile bool pcm_notify_enabled;
static volatile bool imu_sleep;
static volatile bool status_notify_enabled;
static uint8_t status_buf[10];
static int last_volume;
static int64_t locate_until;

#define CTRL_LOCATE_OFF    0
#define CTRL_LOCATE_ON     1
#define CTRL_RECORD_START  3
#define CTRL_RECORD_PAUSE  4
#define CTRL_RECORD_STOP   5

enum pendant_record_state {
	REC_STATE_IDLE = 0,
	REC_STATE_RECORDING = 1,
	REC_STATE_PAUSED = 2,
};
static volatile enum pendant_record_state rec_state = REC_STATE_IDLE;
static void led_set(const struct gpio_dt_spec *l, int on)
{
	if (gpio_is_ready_dt(l)) {
		gpio_pin_set_dt(l, on);
	}
}

static void note_led(bool on)
{
	led_set(&led_blue, on ? 1 : 0);
}

static void status_notify(int volume);
static void mic_set_run(bool on);
static void ble_apply_conn_params(bool pcm_stream);
static struct bt_conn *current_conn;
static uint16_t pcm_seq;
static bool mic_running;

#define BTN_EV_NONE     0
#define BTN_EV_SINGLE   1
#define BTN_EV_DOUBLE   2
#define BTN_EV_LONG     3
#define BTN_EV_LONG_UP  4
#define BTN_STABLE_TICKS 3
#define BTN_LONG_MS      700
#define BTN_DOUBLE_MS    400

static uint8_t btn_event;
static uint8_t btn_seq;
static bool btn_ok;
static bool btn_raw;
static bool btn_pressed;
static uint8_t btn_same;
static uint8_t btn_clicks;
static bool btn_long_done;
static bool btn_note_held;
static int64_t btn_press_ms;
static int64_t btn_release_ms;

/* Idle: 250 ms green every 2 s. Red is only for an active meeting.
 * Locate: fast RGB flash so you can spot the board in a bag or on a desk.
 */
static bool locate_active(void)
{
	return locate_until != 0 && k_uptime_get() < locate_until;
}

static void leds_update(void)
{
	if (locate_active()) {
		const bool flash = (k_uptime_get() % 360) < 180;

		if (pcm_notify_enabled || btn_note_held || rec_state != REC_STATE_IDLE) {
			led_set(&led, 1);
			led_set(&led_green, 0);
			led_set(&led_blue, flash);
			return;
		}
		led_set(&led, flash);
		led_set(&led_green, flash);
		led_set(&led_blue, !flash);
		return;
	}

	if (rec_state == REC_STATE_RECORDING || (pcm_notify_enabled && rec_state != REC_STATE_PAUSED)) {
		/* Recording active: Red LED solid ON */
		led_set(&led_green, 0);
		led_set(&led, 1);
		led_set(&led_blue, btn_note_held ? 1 : 0);
		return;
	}

	if (rec_state == REC_STATE_PAUSED) {
		/* Recording paused: Blue LED pulses (500 ms) */
		led_set(&led, 0);
		led_set(&led_green, 0);
		led_set(&led_blue, (k_uptime_get() % 1000) < 500 ? 1 : 0);
		return;
	}

	if (btn_note_held) {
		led_set(&led_green, 0);
		led_set(&led, 0);
		led_set(&led_blue, 1);
		return;
	}

	/* Idle: Heartbeat green (250 ms every 2s) */
	led_set(&led, 0);
	led_set(&led_green, (k_uptime_get() % 2000) < 250 ? 1 : 0);
	led_set(&led_blue, 0);
}

static void btn_emit(uint8_t ev)
{
	static const char *names[] = {
		"none", "single", "double", "long-down", "long-up",
	};

	btn_event = ev;
	btn_seq++;
	if (btn_seq == 0) {
		btn_seq = 1;
	}
	printk("BTN %s seq=%u\n",
	       ev < ARRAY_SIZE(names) ? names[ev] : "?", btn_seq);
	status_notify(last_volume);
}

static void btn_work_fn(struct k_work *work)
{
	bool raw;
	int64_t now;

	ARG_UNUSED(work);

	if (!btn_ok) {
		return;
	}

	raw = gpio_pin_get_dt(&user_btn) > 0;
	now = k_uptime_get();

	if (raw != btn_raw) {
		btn_raw = raw;
		btn_same = 1;
	} else if (btn_same < 255) {
		btn_same++;
	}

	if (btn_same == BTN_STABLE_TICKS && raw != btn_pressed) {
		btn_pressed = raw;
		if (btn_pressed) {
			btn_press_ms = now;
			btn_long_done = false;
			if (btn_clicks == 1 &&
			    (now - btn_release_ms) > BTN_DOUBLE_MS) {
				btn_clicks = 0;
			}
		} else if (!btn_long_done) {
			btn_release_ms = now;
			btn_clicks++;
			if (btn_clicks >= 2) {
				btn_emit(BTN_EV_DOUBLE);
				btn_clicks = 0;
			}
		} else {
			btn_clicks = 0;
			if (btn_note_held) {
				btn_note_held = false;
				note_led(false);
				leds_update();
				if (imu_sleep) {
					mic_set_run(false);
				}
				btn_emit(BTN_EV_LONG_UP);
			}
		}
	}

	if (btn_pressed && !btn_long_done &&
	    (now - btn_press_ms) >= BTN_LONG_MS) {
		btn_long_done = true;
		btn_clicks = 0;
		if (rec_state != REC_STATE_IDLE) {
			/* Long press while recording or paused: END session */
			rec_state = REC_STATE_IDLE;
			leds_update();
			btn_emit(BTN_EV_LONG);
		} else {
			btn_note_held = true;
			mic_set_run(true);
			note_led(true);
			leds_update();
			btn_emit(BTN_EV_LONG);
		}
	}

	if (!btn_pressed && btn_clicks == 1 &&
	    (now - btn_release_ms) >= BTN_DOUBLE_MS) {
		btn_clicks = 0;
		/* Single click: cycle IDLE -> RECORDING -> PAUSED -> RECORDING */
		if (rec_state == REC_STATE_IDLE) {
			rec_state = REC_STATE_RECORDING;
		} else if (rec_state == REC_STATE_RECORDING) {
			rec_state = REC_STATE_PAUSED;
		} else if (rec_state == REC_STATE_PAUSED) {
			rec_state = REC_STATE_RECORDING;
		}
		leds_update();
		btn_emit(BTN_EV_SINGLE);
	}
}

static K_WORK_DEFINE(btn_work, btn_work_fn);

static void btn_timer_fn(struct k_timer *timer)
{
	ARG_UNUSED(timer);
	k_work_submit(&btn_work);
}

static K_TIMER_DEFINE(btn_timer, btn_timer_fn, NULL);

static void btn_setup(void)
{
	int err;

	if (!gpio_is_ready_dt(&user_btn)) {
		printk("Button D1 (P0.03) not ready\n");
		return;
	}
	err = gpio_pin_configure_dt(&user_btn, GPIO_INPUT);
	if (err) {
		printk("Button D1 configure failed (%d)\n", err);
		return;
	}
	btn_ok = true;
	btn_raw = gpio_pin_get_dt(&user_btn) > 0;
	btn_pressed = btn_raw;
	btn_same = BTN_STABLE_TICKS;
	btn_press_ms = k_uptime_get();
	btn_long_done = btn_pressed;
	k_timer_start(&btn_timer, K_MSEC(10), K_MSEC(10));
	printk("Button D1 ready (NO→D1, COM→GND, internal pull-up)\n");
}

#define IMU_HIST 16
#define IMU_STILL_STD_MM 80   /* mm/s^2; table noise is small, walk is hundreds */
#define IMU_STILL_HITS 10     /* consecutive still polls before sleep (~10 s) */

static int32_t imu_hist[IMU_HIST];
static uint8_t imu_hist_n;
static uint8_t imu_hist_i;
static uint8_t imu_still_hits;
static bool imu_fetch_ok;

static void mic_set_run(bool on)
{
	if (on == mic_running) {
		return;
	}
	if (dmic_trigger(mic_dev, on ? DMIC_TRIGGER_START : DMIC_TRIGGER_STOP) == 0) {
		mic_running = on;
		printk("PDM mic %s\n", on ? "START" : "STOP");
	}
}

static int32_t imu_mag_mm(void)
{
	struct sensor_value x, y, z;
	int32_t ax, ay, az;

	if (!device_is_ready(imu_dev)) {
		imu_fetch_ok = false;
		return -1;
	}
	if (sensor_sample_fetch_chan(imu_dev, SENSOR_CHAN_ACCEL_XYZ) < 0) {
		imu_fetch_ok = false;
		return -1;
	}
	if (sensor_channel_get(imu_dev, SENSOR_CHAN_ACCEL_X, &x) < 0 ||
	    sensor_channel_get(imu_dev, SENSOR_CHAN_ACCEL_Y, &y) < 0 ||
	    sensor_channel_get(imu_dev, SENSOR_CHAN_ACCEL_Z, &z) < 0) {
		imu_fetch_ok = false;
		return -1;
	}
	imu_fetch_ok = true;
	ax = sensor_value_to_milli(&x);
	ay = sensor_value_to_milli(&y);
	az = sensor_value_to_milli(&z);
	if (ax < 0) {
		ax = -ax;
	}
	if (ay < 0) {
		ay = -ay;
	}
	if (az < 0) {
		az = -az;
	}
	return ax + ay + az;
}

static int32_t imu_var_mm(void)
{
	int64_t sum = 0, var = 0;
	int n = imu_hist_n;
	int32_t mean;
	int i;

	if (n < 4) {
		return 1000000;
	}
	for (i = 0; i < n; i++) {
		sum += imu_hist[i];
	}
	mean = (int32_t)(sum / n);
	for (i = 0; i < n; i++) {
		int32_t d = imu_hist[i] - mean;

		var += (int64_t)d * d;
	}
	return (int32_t)(var / n);
}

static void imu_poll(int volume)
{
	int32_t mag = imu_mag_mm();
	int32_t var;
	bool still;

	if (mag < 0) {
		return;
	}
	imu_hist[imu_hist_i] = mag;
	imu_hist_i = (imu_hist_i + 1) % IMU_HIST;
	if (imu_hist_n < IMU_HIST) {
		imu_hist_n++;
	}
	var = imu_var_mm();
	still = (var < (IMU_STILL_STD_MM * IMU_STILL_STD_MM));

	if (!still) {
		imu_still_hits = 0;
		if (imu_sleep) {
			imu_sleep = false;
			mic_set_run(true);
			printk("IMU wake (var=%d)\n", var);
			status_notify(volume);
		}
		return;
	}

	if (imu_still_hits < 255) {
		imu_still_hits++;
	}
	if (pcm_notify_enabled) {
		return;
	}
	if (!imu_sleep && imu_still_hits >= IMU_STILL_HITS) {
		if (btn_note_held) {
			return;
		}
		imu_sleep = true;
		mic_set_run(false);
		printk("IMU sleep (still var=%d)\n", var);
		status_notify(0);
	}
}

/* 1 MΩ / 510 kΩ divider on XIAO Sense. Gain 1/6, 0.6 V ref → 3.6 V at P0.31. */
#define BAT_DIV_FULL_OHM 1510000
#define BAT_DIV_OUT_OHM  510000

static const struct device *adc_dev = DEVICE_DT_GET(DT_NODELABEL(adc));
static int16_t bat_raw;
static uint16_t battery_mv;
static bool battery_ok;

static int battery_setup(void)
{
	int err;
	struct adc_channel_cfg cfg = {
		.gain = ADC_GAIN_1_6,
		.reference = ADC_REF_INTERNAL,
		.acquisition_time = ADC_ACQ_TIME_DEFAULT,
		.channel_id = 7,
		.differential = 0,
		.input_positive = NRF_SAADC_AIN7,
	};

	if (!device_is_ready(adc_dev)) {
		printk("ADC not ready — no battery SoC\n");
		return -ENODEV;
	}
	err = adc_channel_setup(adc_dev, &cfg);
	if (err) {
		printk("ADC channel 7 setup failed (%d)\n", err);
		return err;
	}
	battery_ok = true;
	printk("Battery ADC ready (AIN7, P0.14 held low)\n");
	return 0;
}

static uint16_t battery_sample_mv(void)
{
	int err;
	int32_t pin_mv;
	struct adc_sequence seq = {
		.channels = BIT(7),
		.buffer = &bat_raw,
		.buffer_size = sizeof(bat_raw),
		.resolution = 12,
	};

	if (!battery_ok) {
		return 0;
	}
	err = adc_read(adc_dev, &seq);
	if (err) {
		return battery_mv;
	}
	pin_mv = bat_raw;
	err = adc_raw_to_millivolts(adc_ref_internal(adc_dev), ADC_GAIN_1_6, 12,
				    &pin_mv);
	if (err || pin_mv < 0) {
		return battery_mv;
	}
	battery_mv = (uint16_t)((pin_mv * (uint64_t)BAT_DIV_FULL_OHM) /
				BAT_DIV_OUT_OHM);
	return battery_mv;
}

static void status_fill(int volume)
{
	int v = volume;

	if (v < 0) {
		v = 0;
	}
	if (v > 65535) {
		v = 65535;
	}
	last_volume = v;
	status_buf[0] = (imu_sleep ? 1 : 0) | (mic_running ? 2 : 0) |
			(device_is_ready(imu_dev) ? 4 : 0) |
			(imu_fetch_ok ? 8 : 0) |
			(nrf_power_usbregstatus_vbusdet_get(NRF_POWER) ? 16 : 0) |
			(btn_note_held ? 32 : 0) |
			(rec_state == REC_STATE_RECORDING ? 64 : 0) |
			(rec_state == REC_STATE_PAUSED ? 128 : 0);
	sys_put_le16((uint16_t)v, &status_buf[1]);
	status_buf[3] = imu_still_hits;
	sys_put_le16(battery_sample_mv(), &status_buf[4]);
	status_buf[6] = btn_event;
	status_buf[7] = btn_seq;
	status_buf[8] = 0; /* reserved */
	status_buf[9] = 0; /* reserved */
}

static ssize_t status_read(struct bt_conn *conn, const struct bt_gatt_attr *attr,
			   void *buf, uint16_t len, uint16_t offset)
{
	status_fill(0);
	return bt_gatt_attr_read(conn, attr, buf, len, offset, status_buf,
				 sizeof(status_buf));
}

static ssize_t control_write(struct bt_conn *conn,
			     const struct bt_gatt_attr *attr, const void *buf,
			     uint16_t len, uint16_t offset, uint8_t flags)
{
	const uint8_t *p = buf;

	ARG_UNUSED(conn);
	ARG_UNUSED(attr);
	ARG_UNUSED(flags);

	if (offset != 0 || len < 1) {
		return BT_GATT_ERR(BT_ATT_ERR_INVALID_ATTRIBUTE_LEN);
	}
	if (p[0] == CTRL_LOCATE_ON) {
		locate_until = k_uptime_get() + 60000;
		printk("Locate ON\n");
	} else if (p[0] == CTRL_LOCATE_OFF) {
		locate_until = 0;
		printk("Locate OFF\n");
	} else if (p[0] == CTRL_RECORD_START) {
		rec_state = REC_STATE_RECORDING;
		mic_set_run(true);
		printk("Control: RECORD_START\n");
		status_notify(last_volume);
	} else if (p[0] == CTRL_RECORD_PAUSE) {
		rec_state = REC_STATE_PAUSED;
		printk("Control: RECORD_PAUSE\n");
		status_notify(last_volume);
	} else if (p[0] == CTRL_RECORD_STOP) {
		rec_state = REC_STATE_IDLE;
		printk("Control: RECORD_STOP\n");
		status_notify(last_volume);
	}
	leds_update();
	return len;
}

static void status_ccc_changed(const struct bt_gatt_attr *attr, uint16_t value)
{
	status_notify_enabled = (value == BT_GATT_CCC_NOTIFY);
	printk("Status notify %s\n", status_notify_enabled ? "ON" : "OFF");
	status_notify(0);
}

static void pcm_ccc_changed(const struct bt_gatt_attr *attr, uint16_t value)
{
	pcm_notify_enabled = (value == BT_GATT_CCC_NOTIFY);
	printk("PCM notify %s\n", pcm_notify_enabled ? "ON" : "OFF");
	if (pcm_notify_enabled) {
		imu_sleep = false;
		imu_still_hits = 0;
		mic_set_run(true);
		ble_apply_conn_params(true);
	} else {
		ble_apply_conn_params(false);
	}
	leds_update();
}

BT_GATT_SERVICE_DEFINE(pendant_svc,
	BT_GATT_PRIMARY_SERVICE(&pendant_svc_uuid),
	BT_GATT_CHARACTERISTIC(&pendant_pcm_uuid.uuid,
			       BT_GATT_CHRC_NOTIFY,
			       BT_GATT_PERM_NONE,
			       NULL, NULL, NULL),
	BT_GATT_CCC(pcm_ccc_changed, BT_GATT_PERM_READ | BT_GATT_PERM_WRITE),
	BT_GATT_CHARACTERISTIC(&pendant_status_uuid.uuid,
			       BT_GATT_CHRC_READ | BT_GATT_CHRC_NOTIFY,
			       BT_GATT_PERM_READ,
			       status_read, NULL, NULL),
	BT_GATT_CCC(status_ccc_changed, BT_GATT_PERM_READ | BT_GATT_PERM_WRITE),
	BT_GATT_CHARACTERISTIC(&pendant_ctrl_uuid.uuid,
			       BT_GATT_CHRC_WRITE |
				       BT_GATT_CHRC_WRITE_WITHOUT_RESP,
			       BT_GATT_PERM_WRITE, NULL, control_write, NULL),
);

static void status_notify(int volume)
{
	status_fill(volume);
	if (!status_notify_enabled || current_conn == NULL) {
		return;
	}
	bt_gatt_notify(current_conn, &pendant_svc.attrs[5], status_buf,
		       sizeof(status_buf));
}

static void mtu_updated(struct bt_conn *conn, uint16_t tx, uint16_t rx)
{
	printk("ATT MTU updated: TX %u RX %u\n", tx, rx);
}

static struct bt_gatt_cb gatt_callbacks = {
	.att_mtu_updated = mtu_updated,
};

static int pcm_notify_chunk(const uint8_t *pcm, size_t pcm_len)
{
	uint8_t pkt[244];
	uint16_t mtu;
	uint16_t payload_max;
	uint8_t frag_count;
	uint8_t frag;
	size_t offset = 0;
	int err = 0;

	if (!pcm_notify_enabled || current_conn == NULL) {
		return 0;
	}
	if (rec_state == REC_STATE_PAUSED) {
		return 0;
	}
	if (imu_sleep && !btn_note_held) {
		return 0;
	}

	mtu = bt_gatt_get_mtu(current_conn);
	if (mtu < (3 + PCM_HDR_SIZE + 1)) {
		return -EINVAL;
	}

	payload_max = mtu - 3 - PCM_HDR_SIZE;
	if (payload_max > sizeof(pkt) - PCM_HDR_SIZE) {
		payload_max = sizeof(pkt) - PCM_HDR_SIZE;
	}

	frag_count = (uint8_t)((pcm_len + payload_max - 1) / payload_max);

	for (frag = 0; frag < frag_count; frag++) {
		size_t n = pcm_len - offset;

		if (n > payload_max) {
			n = payload_max;
		}

		sys_put_le16(pcm_seq, &pkt[0]);
		pkt[2] = frag;
		pkt[3] = frag_count;
		memcpy(&pkt[PCM_HDR_SIZE], pcm + offset, n);

		for (int tries = 0; tries < 8; tries++) {
			err = bt_gatt_notify(current_conn, &pendant_svc.attrs[2],
					     pkt, PCM_HDR_SIZE + n);
			if (err == 0) {
				break;
			}
			if (err != -ENOMEM && err != -EAGAIN) {
				return err;
			}
			k_sleep(K_MSEC(2));
		}
		if (err) {
			return err;
		}

		offset += n;
	}

	pcm_seq++;
	return 0;
}

static void adv_restart_fn(struct k_work *work);

static K_WORK_DELAYABLE_DEFINE(adv_restart_work, adv_restart_fn);
static uint8_t adv_restart_tries;

static void adv_restart_fn(struct k_work *work)
{
	int err;

	ARG_UNUSED(work);

	err = bt_le_adv_start(BT_LE_ADV_CONN_FAST_1, ad, ARRAY_SIZE(ad),
			      sd, ARRAY_SIZE(sd));
	if (err == 0 || err == -EALREADY) {
		adv_restart_tries = 0;
		printk("Advertising restarted as \"%s\"\n", DEVICE_NAME);
		return;
	}
	if (adv_restart_tries < 8) {
		adv_restart_tries++;
		printk("Advertising restart err %d, retry %u\n", err,
		       adv_restart_tries);
		k_work_schedule(&adv_restart_work, K_MSEC(250));
	} else {
		printk("Advertising failed to restart (err %d)\n", err);
	}
}

static void schedule_adv_restart(void)
{
	adv_restart_tries = 0;
	k_work_schedule(&adv_restart_work, K_MSEC(50));
}

static void ble_apply_conn_params(bool pcm_stream)
{
	struct bt_le_conn_param conn_param = {
		/* Recording: 7.5–15 ms like the original good audio path.
		 * Idle: 15–30 ms and a 6 s timeout so a locked iPhone does
		 * not HCI 0x08.
		 */
		.interval_min = pcm_stream ? 6 : 12,
		.interval_max = pcm_stream ? 12 : 24,
		.latency = 0,
		.timeout = 600,
	};

	if (current_conn == NULL) {
		return;
	}
	bt_conn_le_param_update(current_conn, &conn_param);
}
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
int main(void)
{
	void *buffer;
	size_t size;
	unsigned int chunk = 0;
	unsigned int sent = 0;
	unsigned int dropped = 0;

	if (gpio_is_ready_dt(&led)) {
		gpio_pin_configure_dt(&led, GPIO_OUTPUT_INACTIVE);
	}
	if (gpio_is_ready_dt(&led_green)) {
		gpio_pin_configure_dt(&led_green, GPIO_OUTPUT_INACTIVE);
	}
	if (gpio_is_ready_dt(&led_blue)) {
		gpio_pin_configure_dt(&led_blue, GPIO_OUTPUT_INACTIVE);
	}
	btn_setup();

	printk("Booting Krypton (GATT PCM stream)...\n");

	if (battery_setup() == 0) {
		printk("VBAT ~%u mV\n", battery_sample_mv());
	}

	k_thread_create(&ble_thread_data, ble_stack,
			K_THREAD_STACK_SIZEOF(ble_stack), ble_thread,
			NULL, NULL, NULL, 5, 0, K_NO_WAIT);

	for (int i = 0; i < 50 && !ble_ok; i++) {
		k_sleep(K_MSEC(100));
	}

	if (!device_is_ready(mic_dev)) {
		printk("ERROR: PDM Microphone is not ready in Devicetree.\n");
		return 0;
	}

	struct pcm_stream_cfg stream = {
		.pcm_rate = MAX_SAMPLE_RATE,
		.pcm_width = SAMPLE_BIT_WIDTH,
		.block_size = BLOCK_SIZE,
		.mem_slab  = &rx_mem_slab,
	};

	struct dmic_cfg cfg = {
		.io = {
			.min_pdm_clk_freq = 1000000,
			.max_pdm_clk_freq = 3200000,
			.min_pdm_clk_dc   = 40,
			.max_pdm_clk_dc   = 60,
		},
		.streams = &stream,
		.channel = {
			.req_num_streams = 1,
			.req_num_chan    = 1,
			.req_chan_map_lo = dmic_build_channel_map(0, 0, PDM_CHAN_LEFT),
		},
	};

	if (dmic_configure(mic_dev, &cfg) < 0) {
		printk("ERROR: Failed to configure DMIC\n");
		return 0;
	}
	/* Increase hardware gain from 0dB (0x28) to +10dB (0x3c) for clear voice pickup */
	nrf_pdm_gain_set(NRF_PDM, 0x3c, 0x3c);
	printk("PDM gain +10dB (0x3c), HFXO clock\n");

	if (imu_bringup() == 0) {
		printk("IMU ready (sleep when still, wake on motion).\n");
	} else {
		printk("IMU not ready — sleep stays host-side only.\n");
	}

	if (dmic_trigger(mic_dev, DMIC_TRIGGER_START) < 0) {
		printk("ERROR: Failed to start DMIC\n");
		return 0;
	}
	mic_running = true;

	printk("Microphone is active. Subscribe to PCM notify to record.\n");

	while (1) {
		leds_update();
		if (imu_sleep) {
			imu_poll(0);
			status_notify(0);
			k_sleep(K_MSEC(50));
			continue;
		}

		if (dmic_read(mic_dev, 0, &buffer, &size, 2000) != 0) {
			printk("PDM read timeout — restarting mic\n");
			dmic_trigger(mic_dev, DMIC_TRIGGER_STOP);
			k_msleep(20);
			dmic_trigger(mic_dev, DMIC_TRIGGER_START);
			mic_running = true;
			continue;
		}

		if (pcm_notify_chunk(buffer, size) == 0) {
			if (pcm_notify_enabled) {
				sent++;
			}
		} else {
			dropped++;
		}

		chunk++;
		if ((chunk % 32) == 0) {
			int16_t *pcm_data = (int16_t *)buffer;
			int samples = size / 2;
			int32_t sum = 0;
			int volume;
			int i;

			for (i = 0; i < samples; i++) {
				sum += (pcm_data[i] > 0 ? pcm_data[i] : -pcm_data[i]);
			}
			volume = samples ? (sum / samples) : 0;
			imu_poll(volume);
			status_notify(volume);

			printk("Vol: %4d | bat=%umV notify=%d imu_sleep=%d imu_ok=%d still=%u sent=%u drop=%u seq=%u\n",
			       volume, battery_mv, pcm_notify_enabled, imu_sleep, imu_fetch_ok,
			       imu_still_hits, sent, dropped, pcm_seq);
		}

		k_mem_slab_free(&rx_mem_slab, buffer);
	}

	return 0;
}
